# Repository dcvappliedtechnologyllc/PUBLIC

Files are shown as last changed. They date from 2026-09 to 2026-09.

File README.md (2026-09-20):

# DCV Doyle Vee Jaws — Printed Light-Vee Jaws + Keel Dock for the 4-1/2 in Bench Vise

**DCV Applied Technology, LLC** · [DCV-AT.COM](https://dcv-at.com)

Soft vee jaws for the Harbor Freight **Doyle 4-1/2 in swivel vise (item 57737)**, printed in
one piece each, that bolt on in the vise's own 1/4-20 jaw-screw holes. A 150° vee raised 2 in above the
casting holds rifle fore-ends and AR handguards on a few points of contact, a parallel band below
it clamps flat stock like the steel plates did, and a slot behind the band takes a strip of craft
foam. The dock is a double-vee block with a tee flange that hangs from the jaw tops and drops between them
and carries a swappable top — currently a PMAG stub, so an AR lower can be clamped by its magwell
without a separate vise block.

Parametric OpenSCAD plus a Python pipeline for the debossed branding. Everything regenerates from
source; change one number for a different vise.

<!-- photo: both jaws on the vise, handguard clamped -->
<!-- photo: keel dock + PMAG insert with a lower on it -->

---

## ⚠️ Read this first

- This vise makes **7,700 lb of clamping force**. These jaws are designed for a **200 lbf working
  clamp** — enough to hold a fore-end still for work, not enough to crush it. Snug the handle by
  hand. If you lean on it, the jaws will crack at the counterbores before anything else does.
- Provided **as-is, with no warranty of fitness for any purpose**. See LICENSE.
- Printed parts vary enormously with filament, moisture, printer and slicer. Nothing here
  guarantees the strength of a part you print.
- These are **soft jaws**. Never hammer on work held in them, never use them with the vise's
  anvil or pipe jaws in play, and never clamp anything that could go off.
- Inspect before use. Discard at the first crack at a counterbore, the flange root, or the lip.

---

## Why these exist

The steel plates that come on the vise are 4-1/2 in wide, flat, and 1-1/2 in tall. A rifle
fore-end held in them contacts on two lines, right where the finish is, and anything round rolls.
The usual fixes are magnetic rubber pads (which slide) or a dedicated gun vise (which costs more
than the vise did and takes up a bench).

A **light vee** — 150° included, only 0.27 in deep — touches a round or oval fore-end on two
short lines well below its centreline and holds it without crushing. Raising the apex 2 in above
the casting gets the work clear of the vise body so a handguard or a mag well has room around it.
Below the vee, a **parallel band** stands proud like the original plates so flat stock still
clamps parallel with no jaw change. Between the band and the vee is a **foam slot**: a strip of
2 mm craft foam stands in it and leans against the lower vee face, so finished stock never touches
plastic. The lip in front of that slot is deliberately set back from the band's clamp plane so it
never carries load and can't be crushed — it only holds foam.

The **keel dock** is the second half of the idea. A double-vee keel, the negative of the jaw vee,
drops between the jaws, self-centres as they close, and presents a pocket on top. The PMAG insert
that goes in the pocket is the magwell stub from a standard AR vise block on a base with two
captured nuts. Two 1/4-20 screws up through the keel hold it. Swap the insert, swap the fixture.

---

## What's in the box

| File | What it is | Print orientation | Support |
|---|---|---|---|
| `jaw_4.5in_R2_plain_ONEND_PRINT.stl` | Plain jaw. Print two, or one of these + one branded. | Standing on an end face (as delivered) | None |
| `jaw_4.5in_R2_plain_UPRIGHT_PRINT.stl` | Same jaw upright, if you want both jaws the same way | Upright | Under the saddle only |
| `jaw_4.5in_R2_DCV_public_UPRIGHT_PRINT.stl` | Movable jaw with the DCV wordmark and DCV-AT.COM debossed in the back wedge (cleanest artwork) | Upright | Under the saddle only |
| `jaw_4.5in_R2_DCV_public_ONEND_PRINT.stl` | Same, with 45° ceilings cut into the artwork so it prints on end with no support (strongest) | On end | None |
| `dock_keel_4.5in_v9_ONEND_PRINT.stl` | Keel dock (v9 tee-top; v7/v8 hung on a set-tab and clamped cocked — don't print them) | On an end face ("pop can") | None |
| `dock_mag_insert_PMAG_v5_PRINT.stl` | PMAG magwell insert for the keel (cloned PMAG geometry with its sloped magwell seat, on a nut-trap base). v4 was 1/2 in short and the catch never engaged | Base down | None |
| `rod_clamshell_geissele_A_ONEND_PRINT.stl` | **Draft.** Reaction-rod clamshell: two keel-profile halves that close on a Geissele Reaction Rod (Ø0.995 / 0.745 flats), flats facing the jaws, 0.030 in parting gap, two V-grooves for rubber-band preload, two loose 1/8 in register pins. 3.50 in long; sits at the front end of the jaws so the rod still reaches the barrel extension. Rev B waits on a rod-protrusion measurement | On end, both halves + pins | None |
| `jaw_S_chunk_4.5in_PA612_ONEND_PRINT.stl` | **Rev S test print.** One-piece 4.50 in jaw with the Rev S profile: full tab to the OEM pad (pad goes outboard, proud of the band), 9/32 mounting holes, three 3/8 holes on the through-bolt column. Fit-checks the pad-as-washer idea before the steel plates are ordered. Tab assumes a 0.30 in pad | On end | None |
| `jaw_plate_S_DRAFT.dxf` | **Concept.** Laser-cut 1/4 in steel plate for the Rev S segmented jaw (four per jaw between three printed segments). Outline generated by `CAD/jaw_plate.py`; draft until the OEM pad is measured | — | — |
| `jaw_hole_pattern_R2_test_plate_PRINT.stl` | 0.2 in coupon of the Rev R2 slot pattern (2.40 centres, 9/32 holes) — print first to check your screw spacing | Flat | None |
| `vise_handwheel_E_PRINT.stl` | 6-1/2 in handwheel that clips over the vise's sliding T-bar, full DCV logo and a LEFTY LOOSE / RIGHTY TIGHT arrow arc debossed in the face (bonus part, see below) | Face down | None |
| `vise_handwheel_D_plain_PRINT.stl` | Same wheel, plain face | Face down | None |
| `Doyle Jaws 4.5in J - claude PETG+ proto.3mf` | OrcaSlicer project: PETG proto plate, plain jaw on end + branded jaw upright, P1S 0.6 mm | — | — |
| `Doyle Jaws 4.5in Q + PMAG insert - claude PA612-CF15.3mf` | OrcaSlicer project: the nylon jaw plate — both jaws on end, PA612-CF15 presets baked in (as printed 2026-09-09: 5 walls, 40 % 3D honeycomb) | — | — |
| `PMAG insert - claude PA612-CF15.3mf` | OrcaSlicer project: the insert alone, same presets | — | — |
| `Doyle keel v9 + PMAG insert v5 - claude PET-CF17.3mf` | OrcaSlicer project, sliced: keel v9 on end + insert v5, Polymaker PET-CF17 presets baked in (0.24, 4 walls, 30 % 3D honeycomb, 15 mm³/s, 8 mm brim). 4 h 55 m, 259 g | — | — |
| `Polymaker PET-CF17 @BBL P1S 0.6mm Claude.json` | The PET-CF17 filament preset on its own, importable in Orca | — | — |

The jaws are handed only by the artwork. A plain jaw fits either side. The branded jaw reads
correctly on the **movable** jaw (wedge toward the operator); put it on the fixed side and it
reads from the back of the bench, which is fine if that's where you stand.

<!-- previews/jaw_revJ_public_views.png -->

---

## Hardware

All 1/4-20. The vise's own jaw screws are 1/4-20 button heads (5/32 hex) — they are just too short.

| Qty | Part | Where |
|---|---|---|
| 4 | 1/4-20 × **3/4 in** button-head socket cap screw (5/32 hex) | jaws. The casting's holes are blind and only ~0.2 in deep: 3/4 in through the 0.475 in wall + fender is right; a 0.35 in wall (Rev Q) let 3/4 in bottom out; 1 in and 1-1/4 bottom out. |
| 4 | **1/4 in fender washer, 1 in OD** (5/16 hole), ~1/16 thick | under the button heads — the big washer is what carries the prying load. Its bottom edge hangs 0.15 in below the jaw, over air past the casting's ~3/8 in ledge. A 3/4 in OD SAE flat washer also fits the pocket. |
| 4 | 1/4 in SAE flat washer (the ones that came on the vise are fine) | between the button head and the fender washer — a 1/4-20 button head is only 0.44 in across and a fender washer's hole is 5/16, so this bridges it |
| 2 | 1/4-20 × 1-1/4 in button-head socket cap screw | keel → insert, from below, no washer (the head bears in a Ø0.52 bore) |
| 2 | 1/4-20 hex nut (7/16 AF) | dropped down the insert's hex pockets |
| — | 2 mm craft foam, cut 4-1/2 × ~1-1/4 in | foam slot |
| 2 | 3/16 in (4.8 mm) cable tie, 8 in | handwheel |

---

## Key dimensions

Jaw 4.50 L × 3.75 H × 1.54 D (in). Jaw length equals the casting's plate seat, so the ends line
up with the casting sides.

| Feature | Value |
|---|---|
| Vee | 150° included (faces 15° off vertical), 0.27 deep, apex fillet 1/16 |
| Vee span | ±1.00 about the apex |
| Apex height | 2.75 above jaw bottom = 2.00 above the vise top |
| Mounting face to apex | 0.60 |
| Back wedge | 0.35 deep at the saddle, tapering to nothing at the top (82° face) — carries the artwork |
| Saddle | 0.35 over the casting top × 0.40 thick (the casting only has ~1/4 in of flat behind the face before it rounds off); 0.06 relief at the inside corner for the casting's edge radius |
| Parallel band | 0.325 proud of the vee-edge plane, jaw bottom to 1.45 up |
| Foam slot | 0.10 wide × 0.30 deep, against the vee |
| Lip | 0.145 thick, top flush with the lower vee edge, face 0.08 **behind** the band clamp plane |
| Screw pattern | 2 × slots on **2.40** centres (measured: 1.05 from each end of the seat), 0.35 above the jaw bottom; Ø9/32 through, ±1/8 horizontal, **±0.04 vertical** so the machined ledge sets the height and the saddle just lands on the casting |
| Washer pocket | Ø1.06 for a 1 in fender washer, open through the jaw bottom, **0.475** of plastic behind the washer (in compression; sized so a 3/4 in screw fills the casting's blind hole). On end, the pocket ceiling is a single 45° plane ("shed roof") from the vee-side tangent point up through the open jaw bottom, so every layer grows off the solid vee side; upright, it is a teardrop toward the vee. `pocket_roof = "auto"` picks. Rev Q pointed a teardrop at the vee in both orientations and the on-end pockets drooped; the far pocket's plane runs out the jaw end 0.21 in up, which is cosmetic |
| Edges | Lengthwise edges eased: 1/16 chamfers on bed-side edges, 1/16 fillets on top/vee/band edges; slot floor sharp; end edges 1/16 chamfer |

| Keel | Value |
|---|---|
| Length | 4.50 |
| Width | 2.50 across the apex line, 1.96 at the flange, 2.97 over the flanges; 1.89 tall (bottom trimmed 0.30 below the apex line, flange 0.20 above) |
| Pocket | 2.64 × 1.34 × 0.15 |
| Screws | 2 × Ø9/32 on 1.60 centres, Ø0.52 head bores 1.24 deep from the bottom, 0.50 web under the head |
| Tee flange | 0.50 reach × 0.20 thick both sides, full length; rests on the jaw tops |
| Lift | Keel apex 0.015 above the jaw apex when the flange is down → upper vee faces engage first; lower faces get 0.008 total clearance |
| Lower faces | 0.70 long (bottom trimmed 0.30); keel bottom sits 0.30 above the jaw lips. No tab, no reliefs |

| Insert | Value |
|---|---|
| Base | 2.64 × 1.34 × 0.40 |
| Seat | The source block's 11° sloped shoulder, 0.52 tall at the mag's front tapering to nothing at the rear — the rake of the magwell mouth, so the lower sits flat with the stub fully home. Catch notch 2.1–2.3 above the pocket floor |
| Height | 3.43 over the pocket floor |
| Nut pockets | 2 × 7/16 AF hex (+0.01 clearance), from the base top out the top of the stub — nuts drop in from above |

### Handwheel

Not part of the jaw system, but it lives on the same vise. A 6-1/2 in scalloped disc, 0.47 in thick, with a
Ø1.51 in bore that slides over the vise screw's Ø38 mm hub from the front and a rib across the back carrying
an open channel that drops over the Ø15 mm sliding T-bar on both sides of the hub. The hub locates it, the
bar drives it, and two cable ties (through the plate, across the channel mouth, back through — one each
side of the hub) hold it on. The bar is captured centred, so the ball ends stick out past the rim as spinner
knobs and the scallops are the palm grip. The hub pokes out through the front by however far the bar sits
back in it; nothing has to be measured. Six crush ribs in the bore stand 0.016 in proud each side — tap the
wheel on with a mallet and it stays put. The rib walls stop 0.02 in below the bar top so the ties cinch onto
the bar rather than hovering over it. Prints face down, no support, ~4 oz.

Rev E carries the face art: the full DCV logo in the lower half and "◄ LEFTY LOOSE ▪ RIGHTY TIGHT ►" arced
over the top, debossed 0.027 in (first layer plus two 0.24 mm layers, so the floors land on a layer line).
The words are on the *top* arc on purpose — up there the reader's left is counter-clockwise and right is
clockwise, so the arrows point the way the wheel turns. The art is cut mirrored by `handwheel_face.py`
(manifold3d) from the plain Rev D STL, so it reads correctly off the build plate. Rev C was printed and
fitted; D fixed the bore fit and rib height, E added the face.

**Opening.** The vise opens 4-1/2 in between its steel plates. With the printed jaws the apex
line opens roughly 1.2 in less than the bare seat-to-seat distance and the band faces 2.4 in
less. Round stock seats in the vee before the bands meet down to about 1.15 in diameter; below
that use the band flats.

---

## Design basis

Working load **200 lbf** at the apex line, taken as a cantilever from the casting top.

| Member | At 200 lbf | Comment |
|---|---|---|
| Bending in the block at the casting top | ~1,600 psi | 4.5 × 1.19 section, wedge trimmed to 0.35 |
| Saddle bearing on the casting top | ~450 psi | on the casting's ~1/4 in flat |
| Screw tension (prying, both screws) | ~250 lbf each | a grade-5 1/4-20 proofs at ~2,700 lbf |
| Washer bearing on the plastic | ~350 psi | 1 in fender washer on 0.475 of plastic (3/4 in: ~600). With only the small washers the vise ships with it is ~3,000 — use the big ones. |

Loads at the top of the vee instead of the apex are 1.5× these. Against PETG that's a margin of
about 15 on the washer bearing with the 1 in washers and only ~2 with small ones — which is why the working load is 200 and not 500, and why the big washers are not optional. CF nylon roughly
doubles it.

**Load path is designed in-plane.** Every feature is part of one extruded profile, so the plain
jaw prints **standing on an end face** with the layer lines running the length of the jaw, and
the bending stress from clamping never crosses a layer boundary. The branded jaw prints upright
for the sake of the artwork; the clamp load then pulls across layers, and the on-end branded
variant exists for anyone who wants the strong orientation with the mark.

**The lip carries nothing.** Its face sits 0.08 behind the band's clamp plane, and round stock
rides the vee faces above it. A flat piece against the band never reaches it. Earlier revisions
put the lip flush with the band and it was the one thin feature in the load path; setting it back
was cheaper than making it strong.

**The keel hangs from the jaw tops and is clamped by the upper vee faces only.** The tee flange
sets its height on both jaws, flat on flat, so roll and pitch are fixed before the handle moves.
The apex is set 0.015 above the jaw apex: raising a hexagon closes its upper faces and opens its
lower faces by lift × tan 15°, so the upper faces always touch first and their reaction pushes
the keel down onto the flange. Push down → flange → jaw top → saddle → casting; pull up → the
upper wedge tightens. The lower faces are a 0.008 backup. v1–v8 hung on a one-sided set-tab
in the foam slot instead: the keel tipped about 4° on the tab with the vise open and sat 0.04 low,
and a 15° vee (centring component tan 15° = 0.27) cannot out-pull PETG-on-PETG friction
(0.3–0.5) to fix that, so it clamped cocked. A light vee holds a seated keel; it will not seat one.

---

## Printing

Developed on a Bambu P1S, 0.6 mm hardened nozzle, OrcaSlicer. Presets and the sliced plate are in
the 3MF.

| Setting | Jaws, PETG proto | Jaws + insert, PA612-CF (as printed) | Keel |
|---|---|---|---|
| Layer | 0.24 mm (0.30 first) | 0.24 mm (0.30 first) | 0.24 mm |
| Walls | 3 | **5** (0.62 mm lines) | 4 |
| Infill | 20 % cross hatch, infill combination on | **40 % 3D honeycomb**, infill combination on | 30 % 3D honeycomb |
| Top / bottom | 4 / 4 | 4 / 4 | 4 / 4 |
| Support | Tree, on build plate only, branded upright jaw only | none (both jaws on end) | none |
| Brim | 6 mm outer | 8 mm outer | 8 mm |
| Seam | Back (mounting face) | Back | — |
| Speeds | — | outer wall 100, inner 150, infill 150, bridge 30 mm/s; max 9 mm³/s | as nylon, max 15 mm³/s |
| Other | — | precise outer wall on, elephant-foot 0.15, classic walls | |

PETG plate time for a pair of jaws is about 5.5 h and 282 g. The plate is flow-limited: a
0.30 mm layer height on the plain jaw saved nothing measurable, so everything runs at 0.24.

| Material | Where | Notes |
|---|---|---|
| **PETG / PETG+** | prototypes, fit checks | 250 °C, textured PEI 75 °C, fan 30–60 %. Slot, lip and screw slots are dimensioned for it. |
| **PA612-CF15** (Polymaker Fiberon) | final jaws + insert | As printed: 295 °C (290 first layer), high-temp plate 60 °C with glue, fan 0–15 % (off for 3 layers, 30 % on overhangs), no chamber control, **door open, top off**, dry 8–12 h at 80 °C and feed from a dryer. 9 mm³/s. Low moisture uptake keeps the slot and vee stable in a shop. Both jaws on end at 5 walls / 40 % 3D honeycomb plus the insert on its own plate fit one 500 g spool. |
| **PET-CF17** (Polymaker Fiberon) | keel | Compression only; no reason for nylon. 290 °C, textured PEI 80 °C first layer / 75 after with glue stick, fan 0–10 %, 15 mm³/s (PA612 ran 9), **door open** per Polymaker (enclosure not needed), dry 70 °C 8 h. Anneal 120 °C 10 h if you want the extra stiffness; not required. |
| PLA | no | Creeps under sustained clamp load at shop temperatures. |

---

## Fitting

1. Print the **hole-pattern coupon** first. Hold it against the casting with the vise's own
   screws; it should go on without forcing. The slots give ±1/8 in, which covers the scatter in
   these castings.
2. Remove the steel plates. The original screws are the right thread (1/4-20) but too short; keep them for the coupon.
3. Set a jaw on the casting: bottom down on the plate-seat ledge, saddle over the casting top, mounting
   face flat on the seat face. The ledge sets the height; the vertical slop in the slots lets the saddle
   land wherever the rough casting top is. Run in the 1/4-20 × 3/4s with the fender washers (small washer under the head, fender under that), snug, not torqued.
4. Close the vise gently until the bands meet and check the bands are parallel and the vee edges
   line up. If they don't, back off a screw and let the slot find it.
5. Cut a strip of 2 mm craft foam 4-1/2 in long, stand it in the slot, lean it back on the lower
   vee face. Trim it flush with the top.

### Keel dock

1. Drop a 1/4-20 nut down each hex pocket in the insert; it lands on the base.
2. Set the insert in the keel's pocket, run the two 1/4-20 × 1-1/4s up from under the keel.
   The head bears up on the keel web, the nut bears down on the base: base and web are clamped.
3. Pull the foam if it stands above the vee edge. Hang the keel on the fixed jaw by its flange
   (it leans on the upper vee face and stays put), close the movable jaw until the flange is down
   on both jaws and the upper faces have it. Push it down as you snug up; it should not move.

### Reaction-rod clamshell (draft, unprinted)

Same double-vee outline as the keel, split down a vertical plane with a D-channel for the rod. The rod's
vise flats face the jaws, so the clamp goes straight through the flats and the torque is taken by the flat
edges, not by friction on the round. Loop two #64 rubber bands (doubled) or 1/16 in O-rings in the grooves
so the shell stays on the rod between jobs; the pins keep the halves from shearing before the vise is on.
The shell is 3.50 in, shorter than the keel, and goes at the **front** end of the jaws: the receiver cannot
sit over these jaws (the rod is 1 in below the jaw tops), so the shell length is what's left of the rod
behind the receiver once the lugs are in the barrel extension. Measure that before printing.

---

## Designing your own fixture

`Notes/Jaw-Mechanics-Handoff.md` explains how the jaw carries load — the cantilever off the 0.75 in face, why the
screws are not the spring, the stiffness ladder from the FE study, and what a vise built for tall soft jaws would do
differently. `Notes/Fixture-Handoff.md` is the one-page version: the vee, the keel section numbers, the pocket and bolt
interface, and the print rules. Start there if you want something that docks in these jaws.

---

## Regenerating

```
CAD/
  doyle_vee_jaw.scad     jaw, every dimension in inches at the top of the file; print_orientation
                         = true rotates it on end. Renders the plain jaw.
  deboss.py              cuts the artwork: jaw STL + SVG -> branded STL, with the 45° ceiling chamfers
                         for on-end printing. --upright for the upright variant, --public for the
                         DCV-AT.COM art, --flip for the fixed-jaw text rotation.
                         needs manifold3d, trimesh, shapely.
  art_logo_public.scad   the wedge artwork (DCV wordmark + URL) -> art_logo_public.svg via OpenSCAD.
  dock_keel.scad         keel; print_on_end = true.
- `CAD/rod_clamshell.scad` → `rod_clamshell_geissele_A_ONEND_PRINT.stl` (`print_on_end = true`; both halves and two pins on one plate).
  mag_insert.py          cuts the magwell stub from a vise-block STL and adds the nut-trap base.
```

Put your own logo in: any SVG of filled paths works in `art_logo_public.scad` in place of the
wordmark. Keep strokes ≥ 1.2 mm for a 0.6 mm nozzle, ≥ 2 mm if you print on end.

Other 4-1/2 in vises: measure the plate seat (jaw length), the casting top above the seat
(`seat_height_in`), and the screw spacing (`screw_cc_in`, `screw_height_in`). Everything else
follows.

---

## Attribution

The jaw, the keel and the deboss pipeline are original to DCV Applied Technology.

The **PMAG insert**'s stub is cloned PMAG geometry — the external form of a Magpul PMAG magazine body,
reproduced so the stub fits an AR-15 magwell the way the magazine does. It was taken from an AR
magazine vise-block STL rather than modelled from scratch; `mag_insert.py` cuts the stub from that
file and adds the base, nut pockets and keel interface, which are new. PMAG is a Magpul trademark;
no affiliation.

Artwork: DCV wordmark and logo © DCV Applied Technology; URL and handwheel lettering set in Orbitron (SIL OFL).

---

## License

Copyright © 2026 DCV Applied Technology, LLC.

Licensed under the **CERN Open Hardware Licence Version 2 — Strongly Reciprocal
(CERN-OHL-S v2)**. You may use, study, modify, manufacture and distribute this design, including
commercially, provided modified versions are released under the same licence with sources
available. See `LICENSE`.

Source location for the purposes of the licence: **https://dcv-at.com**

## Trademark notice

"DCV", "DCV Applied Technology" and "Offensive Physics" are trademarks of DCV Applied
Technology, LLC. The licence covers the design, **not** the marks. If you distribute a modified
version, remove or replace the DCV wordmark and DCV-AT.COM deboss — they are source identifiers,
and leaving them on a part DCV did not produce misrepresents its origin. The artwork is a
separate SVG and a one-line swap in `art_logo_public.scad`; the plain jaw carries no mark at all.
The same goes for the handwheel: use `vise_handwheel_D_plain_PRINT.stl`, or swap `dcv_logo_poly.svg`
in `handwheel_face.py` for your own art.

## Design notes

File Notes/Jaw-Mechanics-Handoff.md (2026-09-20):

# Doyle Vee Jaws — mechanics handoff

What we learned about how a soft jaw actually carries load, written for someone who might design the next one — or the
vise under it — from a clean sheet. Companion to `Fixture-Handoff.md` (the keel and pocket interface) and the Design Log
(the blow-by-blow). Inches throughout. The numbers come from printed parts on a Harbor Freight Doyle 4-1/2 in vise
(57737) and from a 2D plane-strain finite-element model of the jaw section (`CAD/jaw_fea.py`); where a number is from
the model it says so.

## 1. What the jaw is, structurally

A soft jaw on this vise is a **cantilever off a 0.75 in tall mounting face**. That one sentence drives everything.

The casting offers three surfaces: a machined vertical face 0.75 in tall with two blind 1/4-20 holes at 0.35 in up and
2.40 in apart; a machined ledge about 3/8 in deep under it (the plate seat the OEM steel pad sits on); and a rough cast
top with roughly 1/4 in of usable flat behind the face before it rounds away. Above the top there is nothing to lean on.

Our jaw puts the vee apex 2.00 in above the casting top and the jaw top 3.00 in above it, because a rifle upper, a
handguard or a magazine well needs that clearance over the vise body. So the clamp load enters 2–3 in above the last
point of support. Everything below is about what that does.

## 2. The load path under clamp

The clamp load pushes each jaw *toward its own casting*. With the vee faces symmetric the resultant is normal to the
mounting face; with a big round object high on the upper face there is an upward component as well. The moment of
that load about the casting's top edge tips the jaw back over the casting.

Three things resist the tip:

1. **The mounting face in compression.** The jaw's back face bears on the casting from Z = 0 to 0.75. As the moment
   grows the bearing concentrates at the top edge.
2. **The saddle in compression.** The jaw hooks over the casting top (0.35 in reach, 0.40 in thick). Tipping back
   presses the saddle's rear onto the casting top. The arm is short — the flat is only ~1/4 in — but it is there.
3. **The screws in tension.** The screw axis is 0.35 in up; the pivot is at 0.75; the arm is 0.40 in. Against a load
   2.0 in above the pivot that is a **5:1 lever**: screw tension rises five times faster than clamp force *if* the
   joint opens.

The model's answer, which surprised us: with the joint preloaded even modestly (500 lbf per screw) **it never opens
under clamp load.** The clamp pushes the jaw into the casting harder than the moment pulls the bottom away; screw
tension actually *falls* as the vise is tightened (2000 → ~1200 lbf at 1000 lbf of clamp). The 5:1 lever only bites on
pull-away loads — prying a part out, a hammer blow outward — where the joint sees real tension. That is where preload
matters, and where a screw head bearing on printed honeycomb fails first (see §5).

So under clamp the screws are not the spring. What is?

## 3. Where the flex comes from (a stiffness ladder)

Apex deflection toward the casting at 1000 lbf clamp per jaw, from the 2D model, PA612-CF15 as printed (5 walls solid,
40 % 3D-honeycomb core taken as ¼ of solid modulus), ordered from softest to stiffest:

| Configuration | Apex, mil | Note |
|---|---|---|
| R2 jaw, fenders in pockets (idealised as a bonded face) | ~13 | real fenders on honeycomb are worse — local crush |
| Pad outboard, thin printed tab (0.475) | 15.2 | the band overhangs the pad with nothing under it |
| Pad outboard, tab to the band face (0.90–1.00) | 11.4 | the knee; more tab buys nothing |
| + vertical steel tie bolts through the jaw | 10.1–11.0 | prestress does nothing; steel ties buy 5–10 % |
| + 2 × 1/2 in flat-bar ribs in the section plane | 7.1 | |
| + 100 % infill instead of 40 % | 6.4 | the single biggest plastic-only lever |
| + 2 × L-ribs from 1 in bar (1 in below the vee, 1/2 in above) | 4.6 | depth cubed — the foot matters more than a third rib |
| + 4 × L-ribs | 3.3 | |
| **+ 4 × full-profile 1/4 in laser-cut plates (Rev S)** | **1.2** | infill stops mattering (1.19 vs 1.22 at 100 %) |
| Raise 2.0 → 1.5 in (plastic jaw, no steel) | 7.0 | the geometry lever, if the clearance allows it |

Three lessons in that table:

- **Prestress is not stiffness.** Bolts squeezing the plastic do not change its modulus. A steel member only helps if
  it is in the load path *as steel* — a tie on the tension side, or a rib carrying bending.
- **Depth cubed.** Any steel that stays behind the apex line (so the plastic keeps the vee) is worth far more when it
  is wide low down, where the moment is, than when it is tall.
- **Below ~2 mil the vise is the spring.** A 4-1/2 in slide in its ways plus the leadscrew moves several mil on its
  own. Past that point you are polishing the wrong part; four plates is where we stopped.

## 4. The mounting interface — lessons

- **The head must bear on something that does not creep.** A 1 in fender on 40 % honeycomb is ~0.7 in² of cells; at
  2000 lbf that is ~3000 psi and it crushes and creeps, which is exactly what "the flex is at the screws" felt like.
  Putting the OEM steel pad *outboard* — pad → printed tab → casting — spreads each screw over ~1 in² of solid plastic,
  or, with the Rev S plates, onto steel edges directly. Nose-bleed torque becomes safe.
- **Do not thin the root.** A rabbet at the casting face to save screw length is a hinge at the exact section with the
  most moment. The tab should be the full section; the pad stands proud of it.
- **A thin plastic layer in the stack is stiffer than a thick one** (compression stiffness ∝ 1/t), but that term is
  small; what matters is that the pad backs the whole band, not the tab thickness.
- **The blind holes set the screw length**, and the screw length sets how thick the stack can be. Measure hole depth
  early. A 3/4 in screw bottomed through a 0.35 in wall; two M6 flats fixed it that day; the design fix was the wall.
- **Slots versus holes.** Horizontal slots (±1/8) let the jaw find the casting's hole spacing; vertical slop (0.08)
  lets the machined ledge set the height while the saddle lands wherever the rough top puts it. Once the spacing is
  confirmed, holes locate better than slots and the pad takes the shear.
- **Preload is a take-up-the-slop lever**, not a stiffness lever. It flattens the printed face onto the rough casting
  and it is what holds the joint shut under pull-away. Plain Grade 8 nuts on a preloaded joint; no nylocks.

## 5. Material and print orientation

- **Print on end.** Every feature of the jaw lives in the extruded profile, so standing the part on its end face
  turns pockets, slots, roofs and holes into vertical walls. It also puts the layer lines *along the length*, so
  bending in the section plane never loads a layer interface — CF nylon's weak axis is the interlayer, and it is out
  of the load path.
- **"A roof is only a roof in one orientation."** A 45° ceiling that grows off solid in the upright print grows out of
  open air on end. Face-angle checks are not enough — slice it (`CAD/printcheck.py`) and look for material that has
  nothing under it a layer down.
- **Walls vs infill.** With five 0.6 mm walls the skin carries the vee; the core mostly carries compression. Going 40 →
  100 % infill halves the deflection of an all-plastic jaw and does nothing once there is steel inside. Choose infill
  by which jaw you are building.
- Materials as used: PETG for shape protos; PA612-CF15 for jaws and inserts (295/290 °C, high-temp plate 60 °C + glue,
  fan 0–15 %, 9 mm³/s, 5 walls, 40 % 3D honeycomb; door open, dryer feed); PET-CF17 for the keel (290 °C, textured PEI
  80 °C + glue, fan 0–10 %, 15 mm³/s, 4 walls, 30 %; door open).

## 6. The vee

- **15° off vertical (150° included) is a light vee.** It self-locates a round or a keel but it will not self-centre
  against friction: the centering component is tan 15° = 0.27, and plastic-on-plastic friction is 0.3–0.5. Anything
  that sits in the vee must be located *before* the handle moves. That is why the keel grew a tee flange that rests on
  the jaw tops and a 0.015 in lift so its upper faces engage first and push it down onto the flange.
- **Apex height sets the lever.** Every inch of raise is a linear increase in moment and a cubic increase in cantilever
  deflection. Put the apex as low as the clearance behind the jaw allows and no lower than the work needs.
- **The lip never bears.** The band below the vee carries a foam slot and a lip that holds a foam sheet against the
  face; nothing structural hangs on it, and the keel's history (v1–v8 cocked on a tab in that slot) is the reason.

## 7. If you were designing the vise itself

The soft jaw fights the vise it sits on. A vise built for tall soft jaws would:

- **Make the mounting face tall** — 2–3 in, not 0.75 — so the jaw is a plate bolted to a wall, not a cantilever off a
  curb. Every problem in §2–4 shrinks with the face height.
- **Put the screws high and spread them**, or use four. With the pivot at the top edge of the face, screws near the
  top have the long arm; ours sit 0.40 in below the pivot. Even two screws at mid-height on a 2.5 in face would cut the
  lever from 5:1 to about 1:1.
- **Give the jaw a keyed seat**: a machined step or a pair of dowels that take shear and locate the jaw, so the screws
  only preload. Then slots and slop go away.
- **Provide a steel backer as part of the vise** — the equivalent of our outboard pad, but designed in: a full-height
  steel plate the soft jaw bolts to, with the vise's own screws bearing on steel. That is the Rev S plate stack done
  once in the casting instead of four times in every jaw.
- **Keep the jaw tops as a datum.** The tee-flange trick only works because both jaw tops are co-planar; make that a
  machined feature and every fixture can hang from it.
- **Know the slide's own stiffness.** Ours is the floor at a couple of mil per 1000 lbf; a heavier slide or a shorter
  overhang raises the floor and makes the jaw improvements visible.

## 8. Where the numbers came from

`CAD/jaw_fea.py`: 2D plane-strain Q4 raster mesh of the section at 0.025 in, compression-only penalty contact on the
casting face, ledge and casting top, screw preload and axial stiffness at Z = 0.35, PA612-CF15 as 750 ksi solid with a
core at ¼ of that, steel at 30 Msi, 1000 lbf per jaw split on both vee faces (keel case) or high on the upper face
(big-round case). It is a section model: it cannot see local crush under a washer, and it smears ribs over the length.
Treat the ratios as solid and the absolute mils as ±30 %.

Files: `CAD/doyle_vee_jaw.scad` (jaw, Rev R2), `CAD/jaw_plate.py` (Rev S steel plate DXF), `CAD/build_revS_chunk.py`
(one-piece Rev S test jaw), `CAD/printcheck.py`, `Notes/Design-Log.md`, and the 3D viewer in `CAD/viewer/`.

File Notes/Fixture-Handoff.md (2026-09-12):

# Doyle Vee Jaws — fixture handoff

How to design something that docks in these jaws. Everything below is inches; the source of truth is
`CAD/dock_keel.scad` (keel) and `CAD/doyle_vee_jaw.scad` (jaw). Parts are modelled in mm, parameters in inches.

## The jaw vee (what you dock into)

Two printed jaws on a Harbor Freight Doyle 4-1/2 in vise (57737), 4.50 in long, each with a **light vee**:
a 150° included vee (faces tilted 15° off vertical), apex 2.00 in above the casting top, faces reaching 1.00 in
above and below the apex. The jaw top is flat, 3.00 in above the casting. Below the vee is a band with a foam slot;
the band never carries a fixture.

Frame used in every file: **X along the jaws, Y across the vise (toward the workpiece = away from that jaw's casting),
Z up.** For a fixture the useful datum is the *apex line* of the two vees; with the keel seated the apex lines are
**2.50 in apart** and the jaw tops are 0.985 in above them (see lift, below).

## The keel: the standard foot

The keel (`dock_keel_4.5in_v9_ONEND_PRINT.stl`, v9) is the negative of the two vees — a hexagon in section — with a
tee flange on top. Anything that needs to sit in the vise should either *be* a keel (same section, your own top) or
*bolt to* the keel's pocket. The numbers, in the section plane (Y across, Z up, Z = 0 at the jaw-bottom datum the
keel's own files use):

| Feature | Value | Why |
|---|---|---|
| Length along X | 4.50 | = the vise plate seat; clamps over the casting, no wing loading |
| Width at the apex line | 2.500 | the jaws close to 2.50 at apex when seated |
| Vee faces | 15° off vertical, ±1.00 from the apex line | must match the jaws |
| Width at the flange underside (0.985 above apex) | 1.972 | = 2.50 − 2 × 0.985 × tan 15° |
| **Tee flange** | 0.50 reach each side × 0.20 thick, underside 0.985 above the apex | rests on both jaw tops; sets roll and pitch before the handle is touched |
| Overall width over the flanges | 2.972 | |
| **Lift** | keel apex sits 0.015 above the jaw apex when the flange is down | upper faces engage first and push the keel *down* onto the flange; lower faces get 0.008 total clearance |
| Bottom trim | keel bottom 0.30 above the lower vee edge line | lower faces are a 0.70 backup; bottom clears the foam lips |
| Section height | 1.885 (bottom trim to flange top) | |

Rules that came from broken prints: no fin or tab into the foam slot (v1–v8 hung on one and clamped cocked); a 15°
vee cannot self-centre against plastic-on-plastic friction, so a fixture must be located *before* the handle moves —
that is what the flange and the lift do. Push down → flange; pull up → the upper wedge tightens.

## The pocket: how tops attach

The keel top has a pocket for a swappable insert, and two screws come **up from below**:

- Pocket: 2.64 × 1.34, 0.15 deep, 0.01 clearance each side, centred on the keel.
- Two 1/4-20 × 1-1/4 button heads on **1.60 c-c** along X, 9/32 clearance holes through the keel, Ø0.52 counterbores
  from the keel bottom (a 5/32 T-handle reaches them between the jaws). 0.50 in of keel web is left under the heads.
- The insert has a 0.40 in thick base that fills the pocket and two hex pockets (7/16 AF, from the top) that trap 1/4-20
  nuts: the nut bears down on the base, the head bears up on the keel web, so base + web are actually clamped.
- All hardware in this project is 1/4-20. Do not introduce M6.

So a new top = a 2.64 × 1.34 × 0.40 base (the pocket is cut 0.01 larger all round) with two nut pockets on 1.60 c-c, plus whatever you want on top of it.
Reference insert: `dock_mag_insert_PMAG_v5_PRINT.stl` (`CAD/mag_insert.py`).

## Variants on the same section

- **Reaction-rod clamshell** (Rev A, draft): the keel section split on a vertical plane with a D-channel for a rod along
  X, so the vise closes the shell on the rod; 0.030 parting gap so the clamp goes through the rod, rubber-band grooves
  for preload, a tongue-and-groove key planned for Rev B. `CAD/rod_clamshell.scad`. If your fixture clamps something
  rather than holding it, start there.
- Anything long along X can overhang the jaws; the section is what matters.

## Printing

Print keels and clamshells **on end** ("pop can", `print_on_end = true`): flange, pocket, bores and channel all become
vertical walls, no support. A roof is only a roof in one orientation and a 45° face is only printable if it grows off
solid — run `CAD/printcheck.py <stl>` before sending anything; it slices at 0.24 and reports unsupported area.
Materials so far: PETG for protos, PET-CF17 for the keel (290 °C, textured PEI 80 °C + glue, fan 0–10 %, door open),
PA612-CF15 for jaws and inserts.

## Files

`CAD/dock_keel.scad` (parameters: `keel_apex_width_in`, `flange_reach_in`, `keel_lift_in`, `bottom_trim_in`, pocket
and bolt sizes), `CAD/mag_insert.py`, `CAD/rod_clamshell.scad`, `CAD/printcheck.py`, and the 3D viewer artifact
(`CAD/viewer/doyle_assembly_viewer.html`) to see how it all sits.

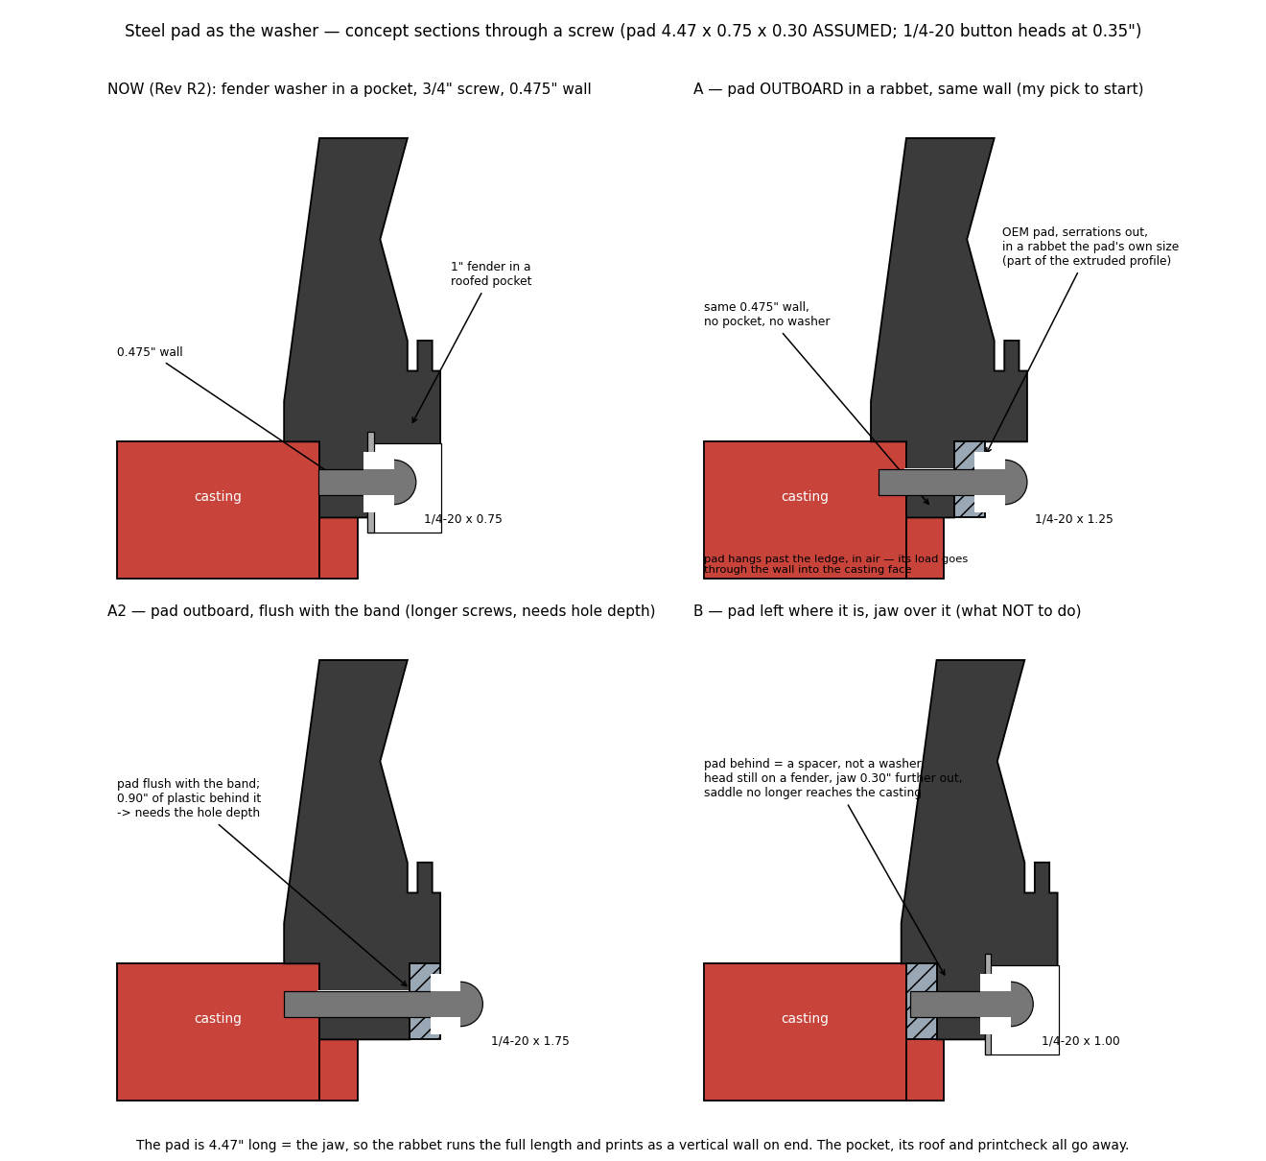
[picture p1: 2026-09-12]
CAD/previews/pad_washer_concepts.png

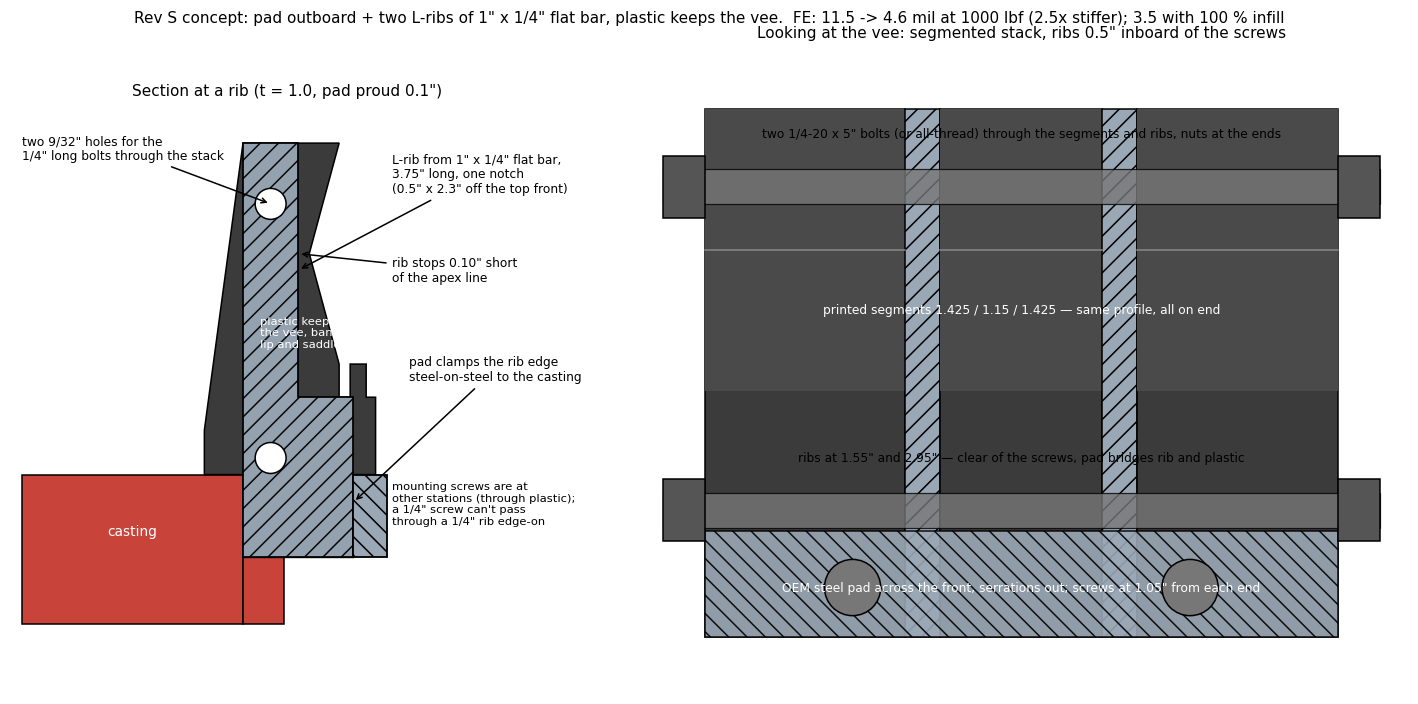
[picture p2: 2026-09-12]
CAD/previews/jaw_rib_concept.png

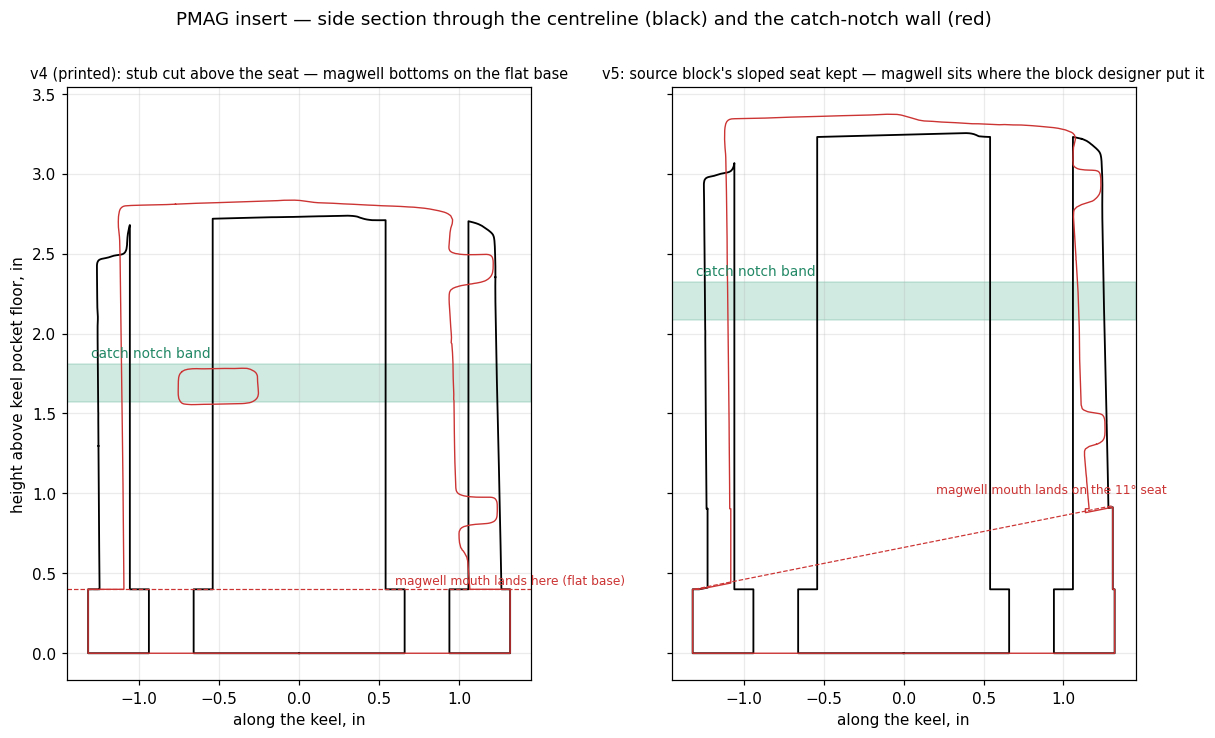
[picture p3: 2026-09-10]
CAD/previews/dock_mag_insert_v5_seat.png

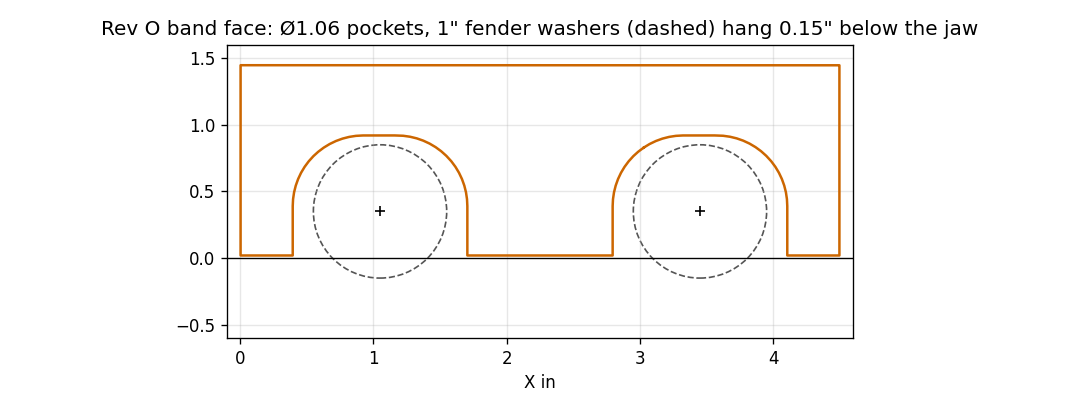
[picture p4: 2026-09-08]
CAD/previews/jaw_revO_bores.png

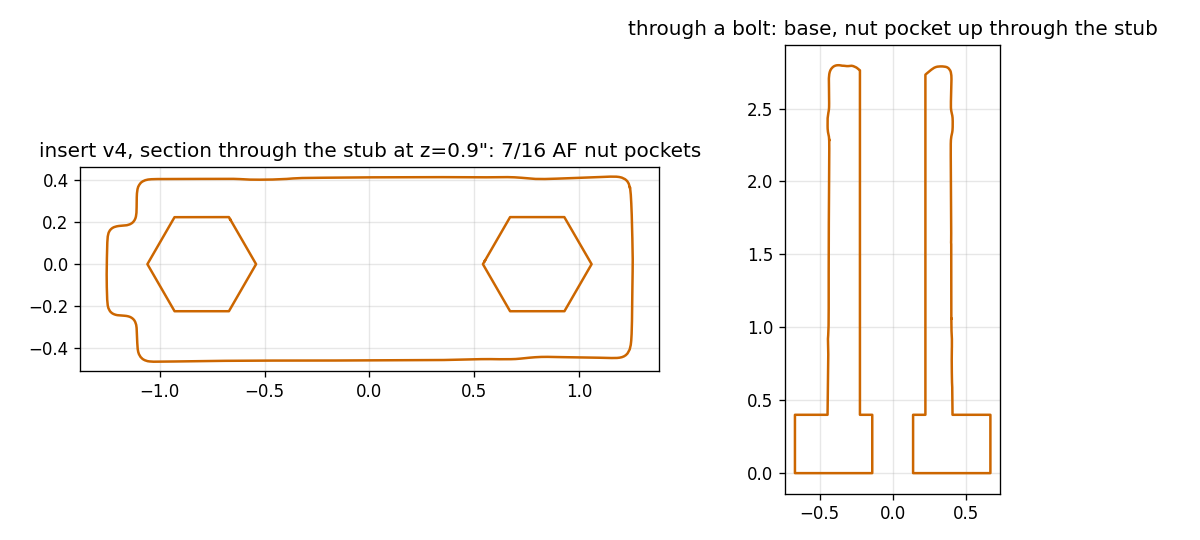
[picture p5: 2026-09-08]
CAD/previews/insert_v4_sections.png

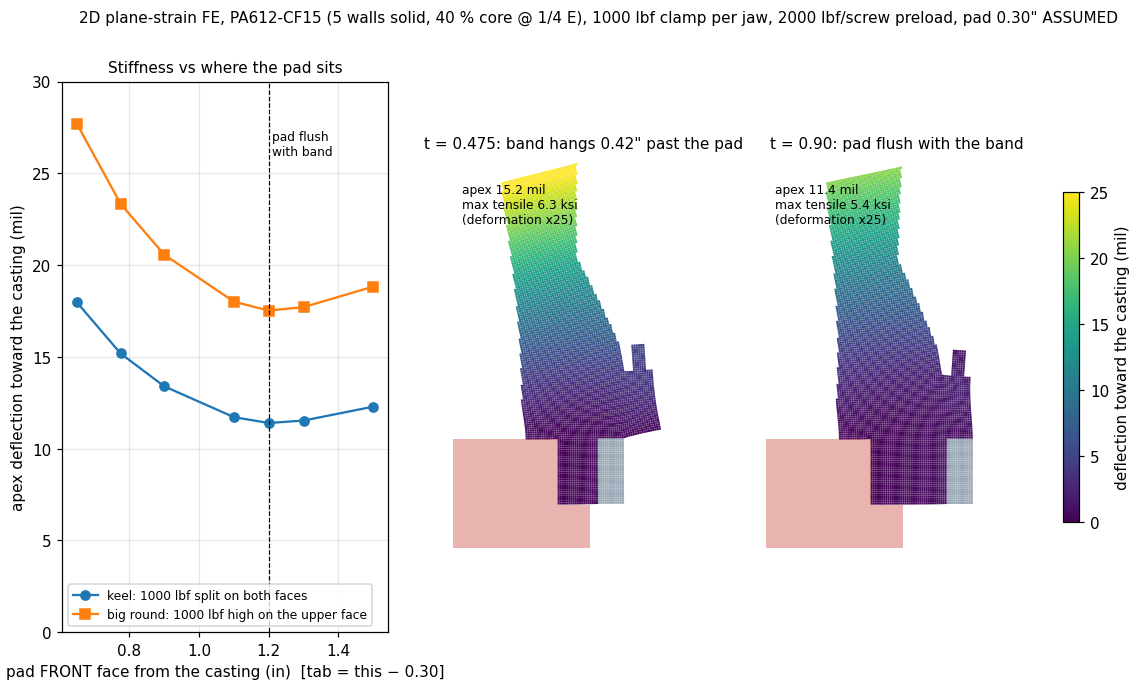
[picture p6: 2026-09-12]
CAD/previews/jaw_fea_pad_sweep.png

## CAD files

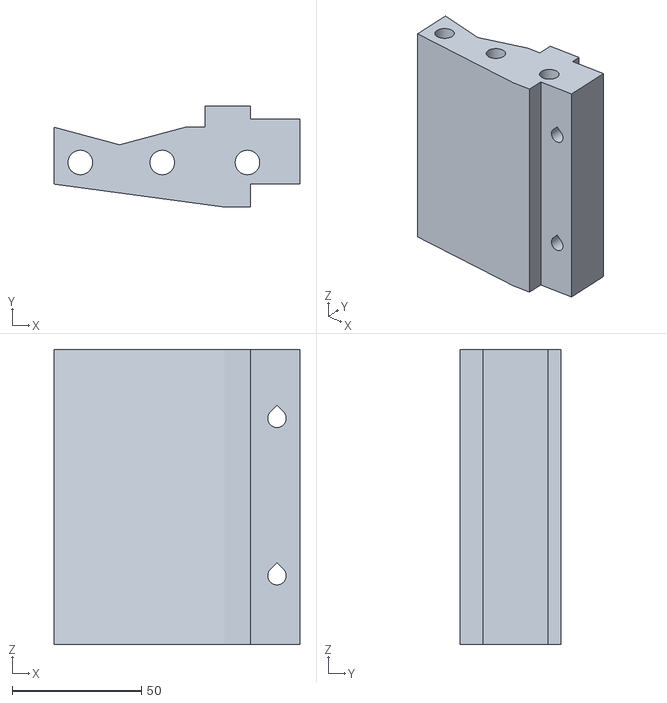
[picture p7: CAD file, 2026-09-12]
CAD/jaw_S_chunk_4.5in_PA612_ONEND_PRINT.stl
95.2 x 39.2 x 114.3

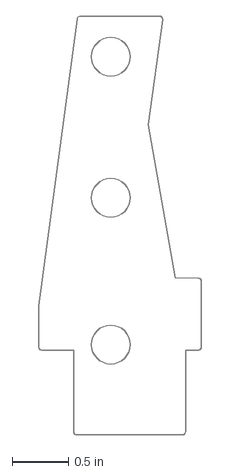
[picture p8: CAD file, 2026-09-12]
CAD/jaw_plate_S_DRAFT.dxf
1.44 x 3.71 in

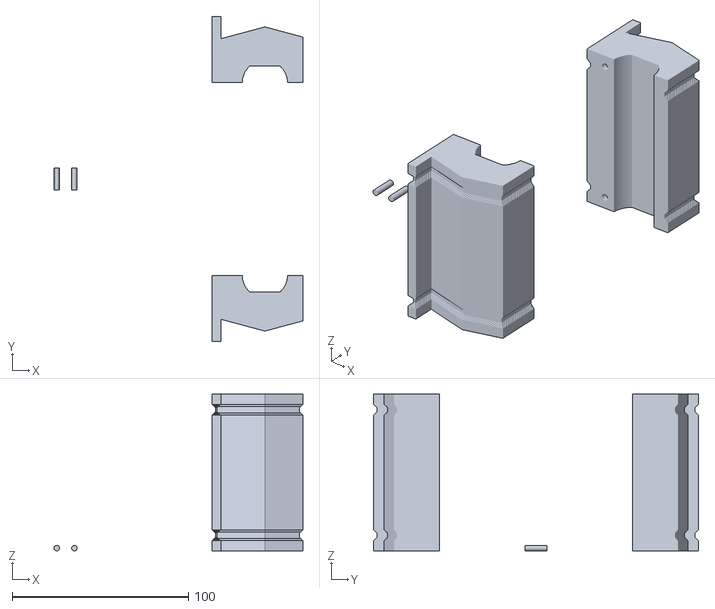
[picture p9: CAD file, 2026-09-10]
CAD/rod_clamshell_geissele_A_ONEND_PRINT.stl
141.1 x 184.4 x 88.9

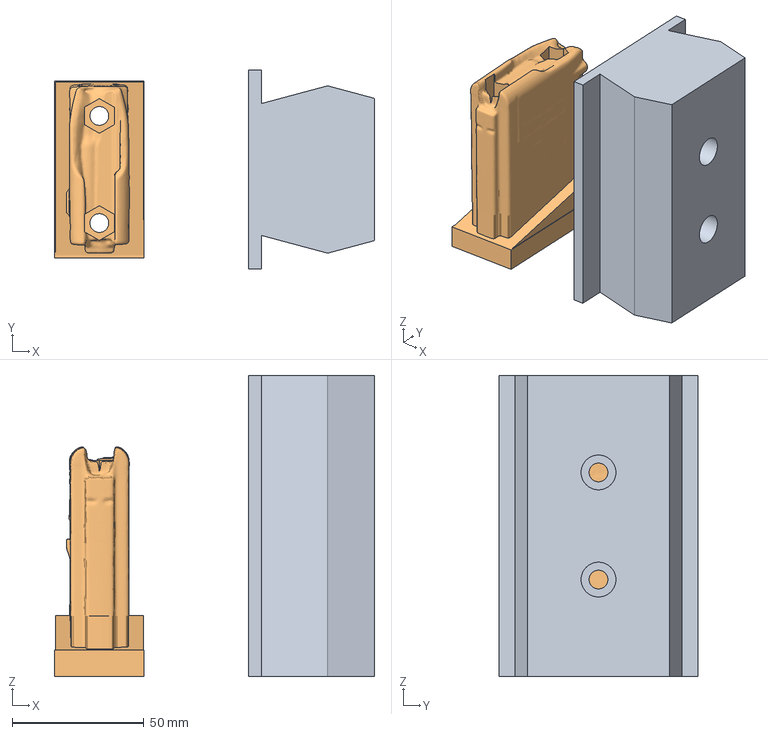
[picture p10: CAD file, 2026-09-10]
CAD/Doyle keel v9 + PMAG insert v5 - claude PET-CF17.3mf
121.4 x 75.5 x 114.3 mm
dock_keel_4.5in_v9_ONEND_PRINT.stl
dock_mag_insert_PMAG_v5_PRINT.stl

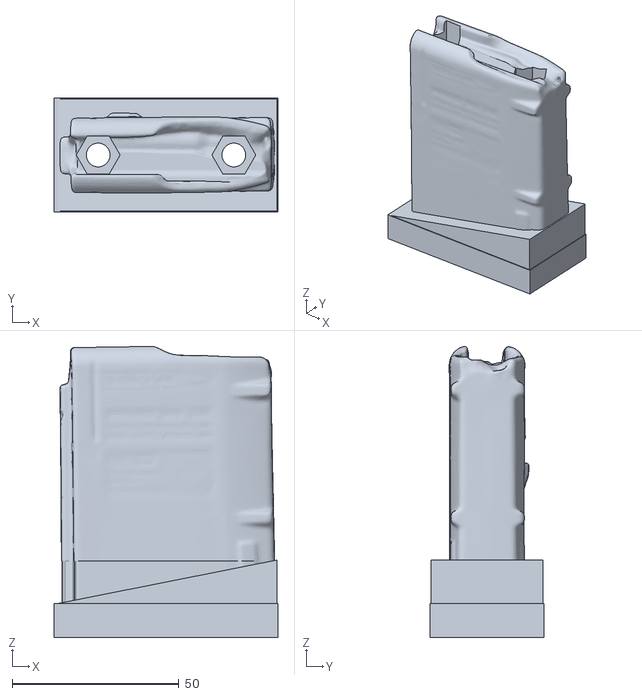
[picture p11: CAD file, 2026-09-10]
CAD/dock_mag_insert_PMAG_v5_PRINT.stl
67.1 x 34.0 x 87.2

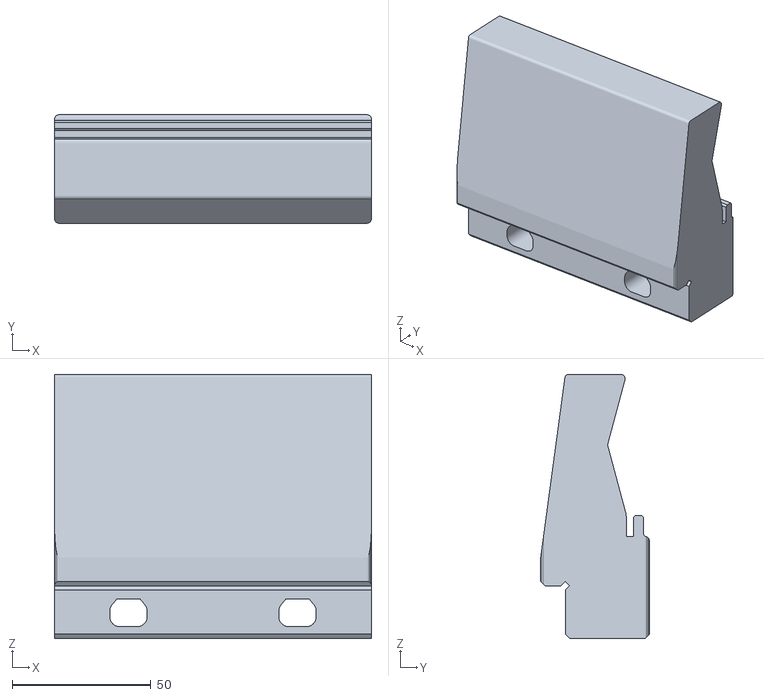
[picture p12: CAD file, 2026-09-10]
CAD/jaw_4.5in_R2_plain_UPRIGHT_PRINT.stl
114.3 x 39.2 x 95.2

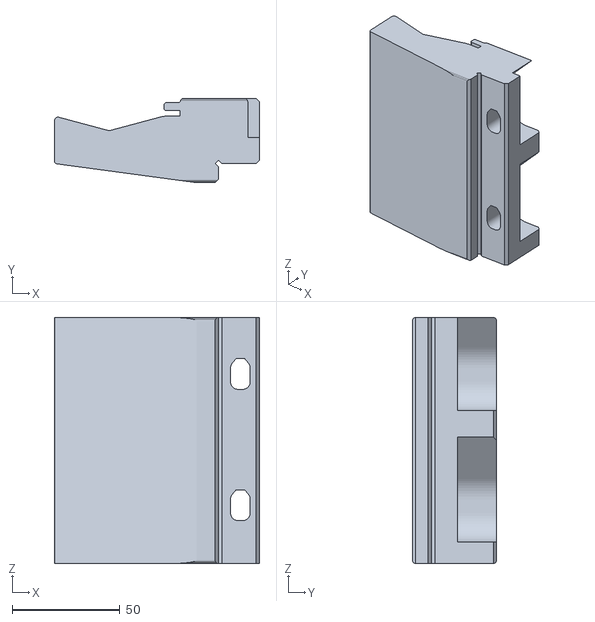
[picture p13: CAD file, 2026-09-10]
CAD/jaw_4.5in_R2_plain_ONEND_PRINT.stl
95.2 x 39.2 x 114.3

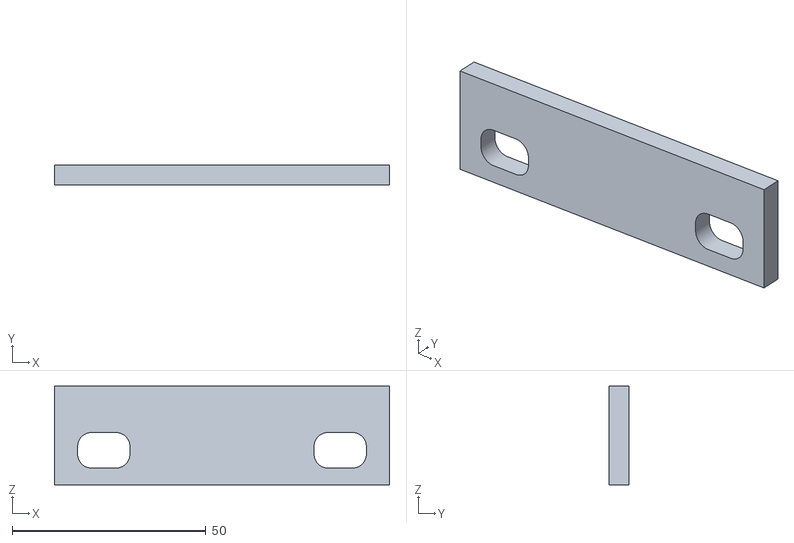
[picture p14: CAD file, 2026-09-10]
CAD/jaw_hole_pattern_R_test_plate_PRINT.stl
86.4 x 5.08 x 25.4

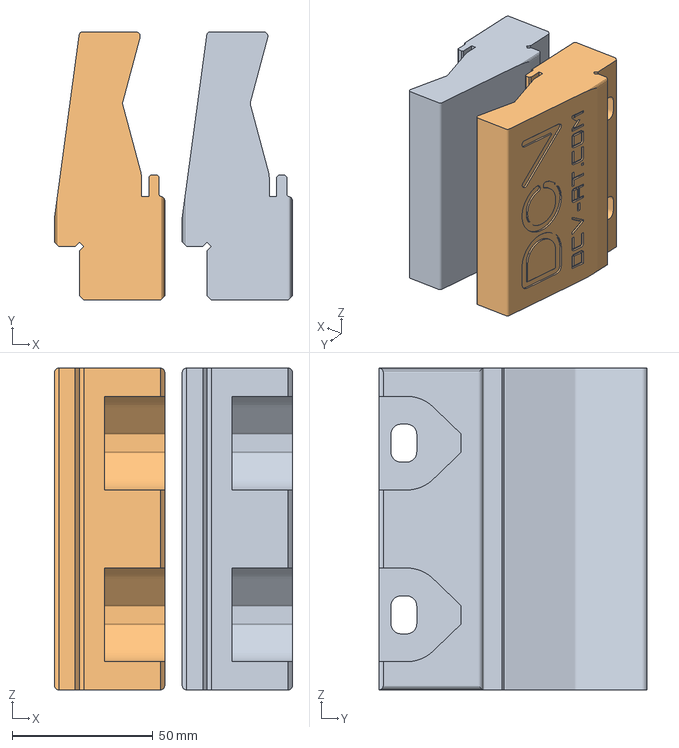
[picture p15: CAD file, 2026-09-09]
CAD/Doyle Jaws 4.5in Q + PMAG insert - claude PA612-CF15.3mf
84.5 x 95.2 x 114.3 mm
jaw_4.5in_Q_plain_ONEND_PRINT.stl
jaw_4.5in_Q_DCV_public_ONEND_PRINT.stl

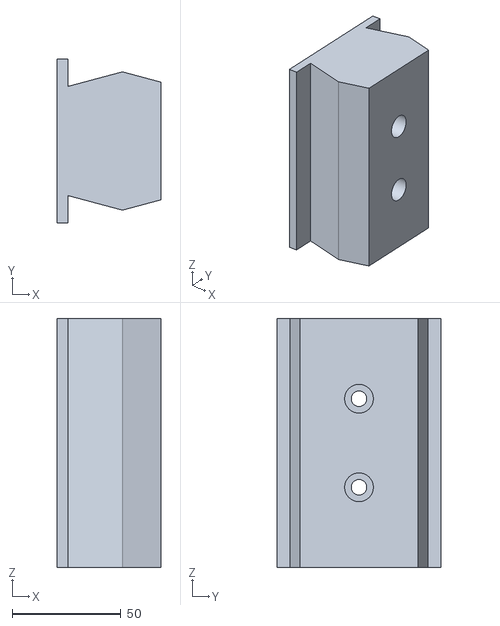
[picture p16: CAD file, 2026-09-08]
CAD/dock_keel_4.5in_v9_ONEND_PRINT.stl
47.9 x 75.5 x 114.3

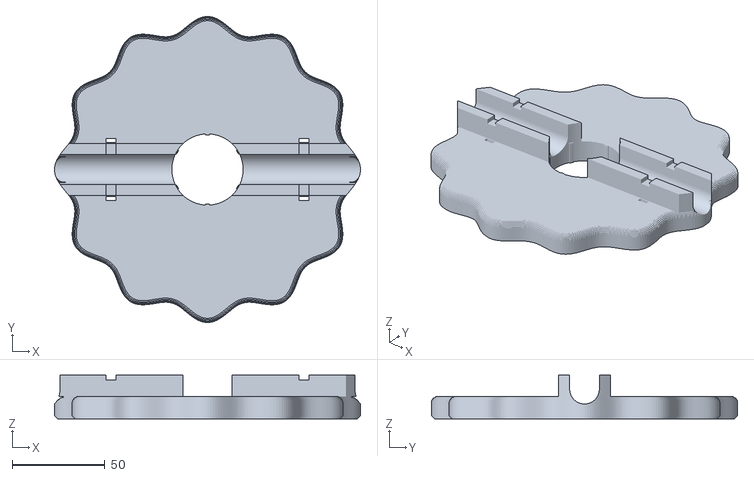
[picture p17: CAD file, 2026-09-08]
CAD/vise_handwheel_E_PRINT.stl
165.0 x 165.0 x 23.5

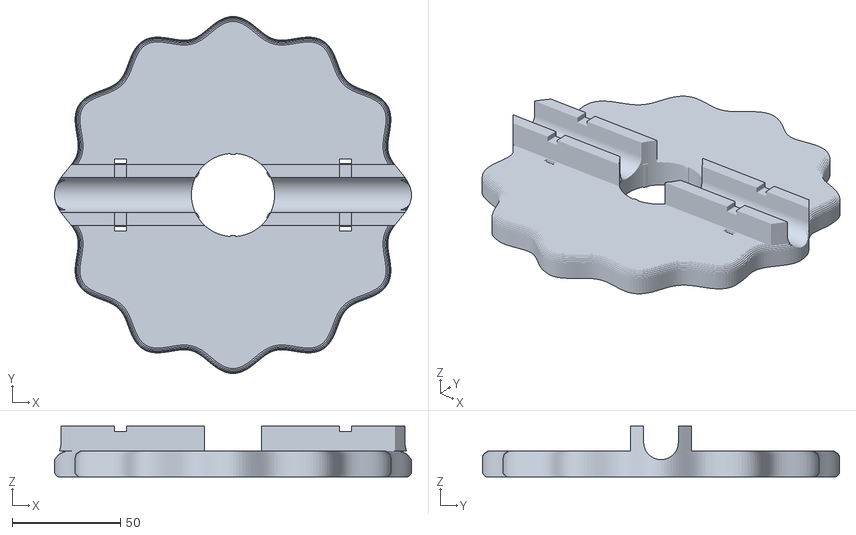
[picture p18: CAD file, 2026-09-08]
CAD/vise_handwheel_D_plain_PRINT.stl
165.0 x 165.0 x 23.5

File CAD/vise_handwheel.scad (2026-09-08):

// Handwheel adapter for the Doyle 4-1/2" vise screw — Rev D geometry (Rev C printed: bore had no interference -> tightened; bar seat
// depth was dead-on -> untouched; rib walls were taller than the bar so the ties hovered -> cut down to just below the bar top so they
// cinch on it). Rev E = this solid + face art (full DCV logo, "LEFTY LOOSE / RIGHTY TIGHT" arc) debossed 0.68 mm into the front face by
// handwheel_face.py (manifold3d), which reads the Rev D STL exported from here. Render this file plain -> vise_handwheel_D_plain_PRINT.stl.
// Slides over the Ø38 hub from the front (through bore), a rib across the back carries an open channel that
// drops over the sliding T-bar (Ø15) on both sides of the hub. Two cable ties, one each side, pass through the
// plate and across the channel mouth to hold the bar in. The hub sticks out through the front — how far depends
// on where the bar sits in the hub, so nothing here needs that number.
// PRINT FACE DOWN (front face on the bed), no support. Units: mm (the vise was measured in mm); inches in comments.

/* [Vise — measured] */
hub_dia        = 38;     // hub OD  (1.50")
bar_dia        = 15;     // T-bar OD (0.59")
ball_dia       = 24;     // ball ends, guess; only used for the preview
bar_len        = 220;    // preview only: 6-3/4" between the rubber washers + ~1" of rubber/ball each end

/* [Wheel] */
wheel_dia      = 165;    // 6.50" — 6-3/4" of bar between the rubber washers; rim stops 1/8" short of each, balls + rubber outside
plate_t        = 12;     // face plate thickness (0.47")
scallops       = 12;     // finger scallops around the rim
scallop_depth  = 4;      // radial amplitude of the scallops
front_chamfer  = 1.5;    // bed-side edge (prints as a 45deg overhang)
back_round     = 3;      // back-side rim edge fillet
hub_clear      = 0.4;    // bore = hub + this (Rev C at 1.0 + ribs came out with no interference at all)
bar_clear      = 1.0;    // channel = bar + this

/* [Crush ribs — tap-on fit on the hub. The bore stays at clearance; six small ribs stand proud of it and
   interfere with the hub, so they crush/shave as the wheel is tapped on and hold it tight. Kept clear of
   the channel (no ribs at 0/180 deg). Lead-in taper on the entry (back) side.] */
crush_ribs        = 6;
rib_interference  = 0.8;    // on diameter: rib crests sit at hub_dia - this (0.031"). Rev C at 0.4 did nothing.
rib_base_w        = 2.4;    // rib width at the bore wall
rib_leadin        = 2.5;    // taper to zero over this much of the entry side

/* [Bar rib + channel] */
rib_wall       = 6;      // channel wall thickness each side
rib_height     = 11.5;   // rib height off the back of the plate: top lands 0.5 mm BELOW the bar top (bar axis at 16, top at 23.5),
                         // so the tie notch floor (21) is under the bar crown and the tie wraps the bar instead of hovering over it
seat_depth     = 4;      // half-round seat for the bar cut into the plate's back face, so the bar nests below the rib floor

/* [Cable ties] */
tie_w          = 5.5;    // slot for a 4.8 mm (3/16") tie
tie_t          = 2.2;
tie_r          = 52;     // radius of the tie stations (mid-span of the exposed bar: hub edge is r=19.5, rim r=82.5)
tie_notch      = 2.5;    // notch across the rib walls so the strap lies flat over the channel mouth
tie_head_recess= 1.5;    // shallow recess on the front face for the strap between the two slots

$fn = 96;

R  = wheel_dia / 2;
HB = hub_dia + hub_clear;      // bore
CW = bar_dia + bar_clear;      // channel width
RW = CW + 2 * rib_wall;        // rib width
BZ = plate_t + seat_depth + 0;  // bar axis height above the front face when seated: seat bottom at plate_t - seat_depth ... see below

// Bar axis sits at z = plate_t - seat_depth + CW/2 (seat is a half-round Ø CW into the back of the plate)
bar_z = plate_t - seat_depth + CW / 2;

module scalloped_disc(h) {
    // rim: R - scallop_depth + scallop_depth*cos(n*theta)  (smooth lobes, nothing to catch a palm)
    pts = [for (i = [0 : 359]) let(t = i, r = R - scallop_depth + scallop_depth * cos(scallops * t)) [r * cos(t), r * sin(t)]];
    linear_extrude(h) polygon(pts);
}

module plate() {
    // stepped chamfer on the bed side and a stepped round on the back side (hull() would convexify the scallops)
    n = 6;
    union() {
        for (i = [0 : n - 1]) {
            z0 = i * front_chamfer / n; d = front_chamfer * (1 - i / n);
            translate([0, 0, z0]) linear_extrude(front_chamfer / n + 0.01) offset(delta = -d) projection() scalloped_disc(1);
        }
        translate([0, 0, front_chamfer]) scalloped_disc(plate_t - front_chamfer - back_round);
        for (i = [0 : n - 1]) {
            a0 = i * 90 / n; a1 = (i + 1) * 90 / n;
            z0 = plate_t - back_round + back_round * sin(a0); z1 = plate_t - back_round + back_round * sin(a1);
            d = back_round * (1 - cos(a1));
            translate([0, 0, z0]) linear_extrude(max(z1 - z0, 0.01) + 0.01) offset(delta = -d) projection() scalloped_disc(1);
        }
    }
}

module rib() {
    // full-diameter rib on the back, trimmed to the disc outline, channel down the middle
    intersection() {
        translate([-R, -RW/2, plate_t - 0.01]) cube([2 * R, RW, rib_height + 0.01]);
        translate([0, 0, plate_t - 1]) scalloped_disc(rib_height + 2);
    }
}

module cuts() {
    // through bore for the hub
    translate([0, 0, -1]) cylinder(d = HB, h = plate_t + rib_height + 2);
    // bar channel: open to the back, full length
    translate([-R - 1, -CW/2, plate_t - seat_depth + CW/2]) cube([2 * R + 2, CW, rib_height + seat_depth + 1]);
    // half-round seat for the bar, sunk into the back of the plate
    translate([0, 0, bar_z]) rotate([0, 90, 0]) cylinder(d = CW, h = 2 * R + 2, center = true);
    // cable-tie stations: two slots through the plate either side of the rib, a notch across the rib walls,
    // and a strap recess on the front face between the slots
    for (s = [-1, 1]) {
        for (t = [-1, 1])
            translate([s * tie_r - tie_w/2, t * (RW/2 + tie_t/2 + 0.5) - tie_t/2, -1]) cube([tie_w, tie_t, plate_t + 2]);
        translate([s * tie_r - tie_w/2, -RW/2 - 1, plate_t + rib_height - tie_notch]) cube([tie_w, RW + 2, tie_notch + 1]);
        translate([s * tie_r - tie_w/2 - 0.5, -(RW/2 + tie_t + 1), -1]) cube([tie_w + 1, RW + 2 * tie_t + 2, tie_head_recess + 1]);
    }
}

module crush_rib_set() {
    crest_r = (hub_dia - rib_interference) / 2;        // where the rib crest sits
    h       = HB / 2 - crest_r;                        // rib height off the bore wall
    angles  = [for (i = [0 : crush_ribs - 1]) i * 360 / crush_ribs + 180 / crush_ribs];   // straddle the channel axis, never on it
    for (a = angles) rotate([0, 0, a])
        hull() {
            // rounded crest, full height minus the lead-in
            translate([crest_r + 0.6, 0, 0]) cylinder(d = 1.2, h = plate_t - rib_leadin, $fn = 24);
            // base at the wall, full height (buried 0.5 into the wall so the union is clean)
            translate([HB / 2 - 0.5, -rib_base_w / 2, 0]) cube([1, rib_base_w, plate_t]);
            // lead-in: crest runs out to the wall at the back face
            translate([HB / 2 - 0.1, 0, plate_t - 0.01]) cylinder(d = 0.2, h = 0.01, $fn = 12);
        }
}

module wheel() {
    union() {
        difference() {
            union() { plate(); rib(); }
            cuts();
        }
        // ribs only where the bore wall exists (outside the bar seat / channel)
        difference() {
            crush_rib_set();
            translate([-R - 1, -CW/2, plate_t - seat_depth + CW/2]) cube([2 * R + 2, CW, rib_height + seat_depth + 1]);
            translate([0, 0, bar_z]) rotate([0, 90, 0]) cylinder(d = CW, h = 2 * R + 2, center = true);
        }
    }
}

module preview_vise() {   // hub + bar + balls, for the section picture only
    %translate([0, 0, bar_z - 14]) cylinder(d = hub_dia, h = 50);          // hub, end face 14 mm in front of the bar axis (guess)
    %translate([0, 0, bar_z]) rotate([0, 90, 0]) cylinder(d = bar_dia, h = bar_len - ball_dia, center = true);
    %for (s = [-1, 1]) translate([s * (bar_len - ball_dia) / 2, 0, bar_z]) sphere(d = ball_dia);
}

wheel();
if ($preview) preview_vise();

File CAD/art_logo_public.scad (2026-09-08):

// Public branded wedge art (option A): DCV wordmark over DCV-AT.COM.  Units mm; wedge face is 4.50 x 2.67 in.
in = 25.4;
wm_w = 3.60*in;          // wordmark width
url_cap = 0.34*in;       // URL cap height
gap = 0.30*in;
// wordmark bbox after resize: width wm_w, height = wm_w * 37/114
wm_h = wm_w * 37/114;
total = wm_h + gap + url_cap;
translate([0, total/2 - wm_h/2]) resize([wm_w, 0], auto = true) import("dcv_wordmark.svg", center = true);
translate([0, -total/2 + url_cap/2]) text("DCV-AT.COM", size = url_cap, font = "Orbitron:style=Bold", halign = "center", valign = "center", spacing = 1.08);

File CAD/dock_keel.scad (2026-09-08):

// Keel dock for the Doyle light-vee jaws — Rev I (v9): TEE TOP. The keel hangs from a flange that rests on the jaw tops
// instead of hanging on a set-tab in the foam slot. Rev H (v8) and everything before it hung on a one-sided 0.07" fin: with the
// vise open the keel tipped ~4deg on the fin, sat 0.04" low, and a 15deg vee (centering component tan15 = 0.27) cannot out-pull
// PETG-on-PETG friction (0.3-0.5) to fix that, so it clamped cocked. Now: flange underside sits on both jaw tops (flat on flat,
// roll and pitch fixed before the handle moves); the keel apex is set keel_lift ABOVE the jaw apex so the UPPER vee faces touch
// first and their reaction pushes the keel DOWN onto the flange ("top taper dominant"). Push down -> flange; pull up -> the
// upper wedge tightens. Bottom of the keel truncated 0.30" so the lower faces are a 0.70" backup with 0.008" clearance and the
// keel bottom clears the lip tops; set-tab and rail reliefs gone. Drops in from the top and hangs on the fixed jaw alone.
// A double-vee keel that is the negative of the jaw vee (15deg faces, 1.00" above and below the apex),
// so it drops between the jaws, self-centers when clamped, and carries a swappable top (mag insert etc.).
// Two 1/4-20 x 1-1/4 button heads come UP through counterbores in the keel bottom, into 1/4-20 nuts dropped down hex
// pockets inside the mag stub; the nuts bear on the insert base, so base + keel web are clamped.
// Print on end ("pop can", print_on_end = true): flange, pocket and bores all become vertical walls, no support.
// Units: parameters in inches, model in mm.

in = 25.4;

/* [Keel] */
keel_length_in     = 4.50;   // = the plate seat width: clamps right over the casting, no wing loading
keel_apex_width_in = 2.50;   // jaw-apex to jaw-apex when clamped (max opening at apex is 3.00")
face_angle_deg     = 15;     // must match the jaws
vee_half_height_in = 1.00;   // must match the jaws (keel is 2x this tall)
end_stops          = false;   // plates at both ends that bracket the jaw ends so the keel can't walk
stop_thick_in      = 0.20;
stop_gap_in        = 0.03;   // clearance to the jaw end faces
stop_overlap_in    = 0.50;   // how far the stops reach onto the jaw ends, each side

/* [Tee top — flange on both sides that rests on the jaw tops. The keel hangs from it. */
top_flange         = true;
flange_reach_in    = 0.50;   // how far the flange reaches over each jaw top (jaw top is 0.87" wide from the vee edge to the back wedge)
flange_thick_in    = 0.20;   // flange thickness, above its underside
keel_lift_in       = 0.015;  // keel apex sits this far ABOVE the jaw apex when the flange is down -> upper faces engage first,
                             // lower faces get 2*lift*tan(15) = 0.008" total clearance; the clamp pushes the keel onto the flange
bottom_trim_in     = 0.30;   // keel bottom raised this much: lower faces 0.70" long, bottom 0.30" above the jaw lip tops

/* [Set tab — RETIRED in v9 (kept for the record). A fin that dropped into the jaw's foam-lip groove. It hung the keel cocked. */
set_tab            = false;
tab_length_in      = 4.50;
tab_thick_in       = 0.07;
tab_clear_in       = 0.01;
tab_depth_in       = 0.26;
rail_relief_in     = 0.08;   // only cut when set_tab is on
rail_relief_wid_in = 0.30;
print_on_end       = false;  // true = stand on an end face for printing

/* [Top-piece interface — Rev B: two M6 x 30 from the TOP through ears on the insert base,
   into M6 nuts in side-entry slots in the keel (nut bears UP on keel material, so the joint actually clamps) */
pocket_len_in      = 2.64;   // insert base footprint (matches the PMAG block tang: 2.64" x 1.34")
pocket_wid_in      = 1.34;
pocket_depth_in    = 0.15;
pocket_clear_in    = 0.01;
bolt_cc_in         = 1.60;   // bolt center-to-center (inside the stub footprint, +/-0.80")
bolt_dia_in        = 0.28;   // 9/32 clearance for 1/4-20
head_cbore_in      = 0.52;   // Ø for a 1/4-20 button head (0.44 dia), from the bottom — no washer, the keel bottom is only 1.96 wide
keel_under_bolt_in = 0.50;   // solid keel web between the head and the pocket floor: 0.50 + 0.40 base + 0.22 nut = 1.12" < 1-1/4 screw

$fn = 48;

L   = keel_length_in * in;
W   = keel_apex_width_in * in;
VH  = vee_half_height_in * in;
DEP = VH * tan(face_angle_deg);
KH  = 2 * VH;                      // keel height
WT  = W - 2 * DEP;                 // width at top and bottom
ST  = stop_thick_in * in; SG = stop_gap_in * in; SO = stop_overlap_in * in;

FR = flange_reach_in * in; FTK = flange_thick_in * in; LIFT = keel_lift_in * in; BT = top_flange ? bottom_trim_in * in : 0;
ZF = KH - LIFT;                                   // flange underside = jaw top plane when seated
WF = W - 2 * (ZF - VH) * tan(face_angle_deg);     // hexagon width at the flange underside
WB = W - 2 * (VH - BT) * tan(face_angle_deg);     // width at the (truncated) bottom
KT = top_flange ? ZF + FTK : KH;                  // keel top (pocket cut from here)
Z0 = BT;                                          // keel bottom

echo(str("keel ", L/in, " x ", W/in, " (apex) / ", WT/in, " (top,bottom) x ", (KT - Z0)/in, " tall (bottom at ", Z0/in, ", flange underside at ",
         ZF/in, ", top at ", KT/in, "); overall width over flanges ", (WF + 2*FR)/in, "; lower-face clearance when seated ",
         2*LIFT*tan(face_angle_deg)/in, "; total length with stops = ", (L + 2*(SG+ST))/in));

module keel_profile() {   // in (Y, Z): hexagon, apex at Z = VH; truncated at the bottom, tee flange at the top
    if (top_flange)
        polygon([[-WB/2, BT], [WB/2, BT], [W/2, VH], [WF/2, ZF], [WF/2 + FR, ZF], [WF/2 + FR, KT],
                 [-WF/2 - FR, KT], [-WF/2 - FR, ZF], [-WF/2, ZF], [-W/2, VH]]);
    else
        polygon([[-WT/2, 0], [WT/2, 0], [W/2, VH], [WT/2, KH], [-WT/2, KH], [-W/2, VH]]);
}

TL = tab_length_in * in; TT = tab_thick_in * in; TC = tab_clear_in * in; TD = tab_depth_in * in;
RR = rail_relief_in * in; RW = rail_relief_wid_in * in;

module keel() {
    union() {
        difference() {
            union() {
                rotate([90, 0, 90]) translate([0, 0, -L/2]) linear_extrude(L) keel_profile();
                if (end_stops)
                    for (s = [-1, 1])
                        translate([s * (L/2 + SG + ST/2), 0, (Z0 + KT)/2])
                            cube([ST, WF + 2 * FR + 2 * SO, KT - Z0], center = true);
            }
            // relief over the foam-lip rails, both bottom edges (keel must hang on the vee faces, not the rails)
            if (set_tab)
                for (sy = [-1, 1])
                    translate([-L/2 - 1, sy > 0 ? WT/2 - RW : -WT/2 - 1, -1]) cube([L + 2, RW + 1, RR + 1]);
            // pocket for the top piece
            translate([0, 0, KT - pocket_depth_in * in])
                linear_extrude(pocket_depth_in * in + 1)
                    offset(r = pocket_clear_in * in) square([pocket_len_in * in, pocket_wid_in * in], center = true);
            // two bolts from below: clearance hole + deep counterbore for the head (4 mm T-handle reaches)
            for (s = [-1, 1]) {
                bx = s * bolt_cc_in * in / 2;
                translate([bx, 0, Z0 - 1]) cylinder(d = bolt_dia_in * in, h = KT - Z0 + 2);
                translate([bx, 0, Z0 - 1]) cylinder(d = head_cbore_in * in, h = (KT - pocket_depth_in * in - keel_under_bolt_in * in) - (Z0 - 1));
            }
        }
        // set-tab: fin hanging below the bottom on the -Y side, sitting in the jaw's foam slot (slot is against the vee-face
        // plane, lip is 0.10" further in, so the fin at 0.01-0.08" from the edge clears the lip). Added AFTER the relief and
        // carried 1 mm up past it into the web, so it is one body with the keel. Above the vee edge it stands in open air.
        if (set_tab)
            translate([-TL/2, -(WT/2 - TC), -TD]) cube([TL, TT, TD + RR + 1]);
    }
}

if (print_on_end) translate([0, 0, L/2]) rotate([0, -90, 0]) keel(); else keel();   // pop can: stands on an end face (bottom at Z0 is irrelevant on end)

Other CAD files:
CAD/jaw_4.5in_R2_DCV_public_ONEND_PRINT.stl
CAD/jaw_4.5in_R_plain_ONEND_PRINT.stl
CAD/jaw_4.5in_R2_DCV_public_UPRIGHT_PRINT.stl
CAD/jaw_4.5in_R_plain_UPRIGHT_PRINT.stl
CAD/PMAG insert - claude PA612-CF15.3mf
CAD/jaw_4.5in_Q_plain_ONEND_PRINT.stl
CAD/doyle_vee_jaw.scad
CAD/Doyle Jaws 4.5in J - claude PETG+ proto.3mf
CAD/jaw_4.5in_N_plain_ONEND_PRINT.stl
CAD/jaw_4.5in_N_plain_UPRIGHT_PRINT.stl
CAD/jaw_4.5in_O_plain_ONEND_PRINT.stl
CAD/jaw_4.5in_O_plain_UPRIGHT_PRINT.stl
CAD/jaw_4.5in_P_plain_ONEND_PRINT.stl
CAD/jaw_4.5in_P_plain_UPRIGHT_PRINT.stl
CAD/jaw_4.5in_Q_plain_UPRIGHT_PRINT.stl
CAD/jaw_hole_pattern_N_test_plate_PRINT.stl
CAD/jaw_hole_pattern_O_test_plate_PRINT.stl
CAD/jaw_hole_pattern_P_test_plate_PRINT.stl
CAD/jaw_hole_pattern_R2_test_plate_PRINT.stl
CAD/rod_clamshell.scad
CAD/vise_handwheel_C_PRINT.stl

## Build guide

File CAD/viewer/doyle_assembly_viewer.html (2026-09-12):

# Doyle Vee Jaws

HF 57737 · 4-1/2 in vise · jaws Rev R2 · keel v9 · insert v5 · wheel Rev E · clamshell A · Rev S concept

AssemblyCLAMPED

## Parts

## Motion

Vise opening2.50 in at apex Movable jaw, casting and screw travel; the keel stays hung on the fixed jaw.

Explode0

## View

Isometric Operator Top Side

## Display

Section at mid-length Wireframe Vise castings and screw (context only)

Drag to orbit, scroll to zoom, right-drag to pan. Geometry is the actual print STLs (insert and wheel lightly decimated); Rev S and the clamshell are concept solids. Castings are placeholders, not the real vise.

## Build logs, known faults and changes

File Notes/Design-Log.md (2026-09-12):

# Doyle Vee Jaws — design log

Why the parts look the way they do, what was tried and rejected, and what is still open.
Written so the reasoning survives without the conversation.

---

## Origin

Wanted: soft jaws for a Harbor Freight Doyle 4-1/2 in swivel vise (57737) that hold rifle
fore-ends and AR handguards on a few points of contact, print on a Bambu P1S with a 0.6 mm
hardened nozzle, and bolt on in the vise's own jaw-screw holes (thought to be M6 at the time; they are 1/4-20).

The vise was measured from ruler photos, not a drawing: plate seat 4.50 in, screw centres
~2.25 in, screw axis ~0.35 in above the plate bottom, and "4 mm hex button heads = M6" — which was wrong: a
1/4-20 button head takes a 5/32 hex (3.97 mm). The vise is imperial. That uncertainty
is absorbed by ±1/8 in slots rather than chased: "it could slide 1/8 inch and be okay."
`seat_height_in = 0.75` (casting top above the plate seat) is still an assumption to be checked
on the first fitted print.

---

## Vee geometry

150° included (faces 15° off vertical), ±1.00 in span, 0.27 in deep. For round stock of
diameter D the apex gap is 1.035·D, so the vee is shallow enough that fore-ends of 1.2–2.5 in
seat on two short lines well below centre and never touch the apex. Steeper vees were rejected:
they grip harder per pound but put the contact higher on the work and need more opening.

The apex is raised 2.00 in above the casting top so a handguard or a magwell has room around it.
Earlier revisions had the apex at the steel-plate height; the raise came from the observation
that a printed jaw can be any shape, so it may as well get the work clear of the vise body.

Contact points: "flattened pyramids" and interrupted (segmented) contact faces were considered
to save filament and cope with irregular fore-ends, and dropped — foam shims on a plain vee do
the same job with no geometry, and the user's stated preference was fewer clever features.

---

## Revision history

| Rev | Change | Why |
|---|---|---|
| A–B (8 in) | 8 in wide jaw, wings past the casting, apex at plate height | first pass; wings were for long fore-ends |
| C | Raised apex, saddle over the casting, transverse ribs on the back | ribs for stiffness with less plastic |
| C2 | **Ribs replaced by a solid back wedge** | ribs were unprintable on end — "how do those ribs support themselves in midair?" Every feature must be part of the extruded profile so it prints as a vertical wall. |
| D | Debossed branding; chamfered ceilings | OpenSCAD's CGAL could not finish the stepped cutter; moved the deboss to a manifold3d/shapely pipeline |
| F (4.5 in) | **Shortened to 4.50 in = the plate seat**; foam groove behind a lip rail | short ARs don't need wings; 4.5 in saves ~30 % filament and the ends now index on the casting sides. Keel dock and PMAG insert added. |
| G | Lip rail thinned to 0.155 | rail crush concern |
| G2/H | **Lip removed, band left as a flat shelf**; section trimmed 29 % (28.4 → 20.3 in³): back-to-apex 0.75 → 0.60, wedge 1.50 → 0.60, saddle 1.50 → 1.25 | "why not remove this? prevents that spot from ever seeing clamping load" — a flush lip was the one thin feature in the load path. Then "rethink the geometry, reduce the cross section, keep height" |
| I | **Slot back with a set-back lip**; saddle cut flush with the wedge base (tail removed); band 0.275 → 0.325 proud | the foam slot was wanted after all, but with a profile that keeps clamping load off it. Lip face 0.08 behind the band plane, 0.145 thick so it isn't fragile. The 0.65 in of saddle past the wedge did nothing structural. |
| R2 | **Shed roof on the on-end pockets** | R1's fix was wrong in the same way Q was, one step removed: a +X teardrop whose bottom-face side grew out of the open pocket — a 45°-shaped cantilever. The face-angle audit passed it. David's markup on the Q section: continue the vee-side 45° tangent line straight up through the jaw bottom, one plane, no crown. That grows off the solid vee side layer by layer, which is the direction that is actually supported. New check, `printcheck.py`, slices every layer and measures material with nothing under it: Q 733 mm², R1 517, R2 90 (all of it the 9/32 hole's 1.8 mm bridge). Far pocket's plane runs out the jaw end 0.21 in up; cosmetic, off the ledge. |
| R | **Pocket roof follows the print orientation; wall under the head 0.35 → 0.475** | Rev Q printed in PA612-CF (2026-09-09, 5 walls / 40 % 3D honeycomb) and came out "super strong", but the top corners of the pockets drooped: the Q roof pointed at the vee (+Z), which is up only for the upright print. On end, +X is up, so the pocket crown and the flat ceiling of the open-bottom notch were 90° overhangs. Audit of the on-end STL: 1,586 mm² of >45° ceiling; Rev R 23 mm² outside the intended bridges. The roof now points along print-up with a 0.40 in flat (10 mm bridge) at the apex and runs at 45° out through the jaw bottom, so the notch has no ceiling; the 9/32 hole gets a small roof too. Second finding: the 3/4 in screws bottomed in the blind holes at the 0.35 wall — the holes are ~0.2 in deep, not the 0.34 assumed at Rev P — fixed on the vise with two M6 flats, so the wall is now 0.475 (= 0.35 + 0.125). Lesson recorded in CLAUDE.md: a roof is only a roof in one orientation; audit every on-end export. |
| Q | **Teardrop roof on the washer pockets** | Orca flagged the Ø1.06 round pocket as a floating cantilever on the on-end print (its crown goes flat). A 45° roof with a 1/4 in flat at the apex fixes it in either orientation; apex 1.14 up, band top 1.45. The residual Orca warning on the on-end jaws is the 9/32 hole crown, a 7 mm bridge — ignored. |
| P | **Wall under the washer 0.50 → 0.35** | The casting's screw holes are blind: 1-1/4 bottoms out, 1 in wasn't on the shelf, 3/4 mounted but with only 0.19 of thread. The wall behind the washer is in pure compression, so it can be thin; 0.35 gives a 3/4 in screw 0.34 in (7 turns) of engagement. |
| O | Washer pockets Ø0.82 → **Ø1.06 for 1 in fender washers** | Only 1 in fenders on the shelf. Since the pocket is open through the bottom and the washer sits past the ledge, OD is free up to the pocket; 1 in hangs 0.15 below the jaw over air. Bearing ~350 psi. A small washer under the head bridges the fender's 5/16 hole. |
| N | **1/4-20 hardware throughout** (jaw, keel v7, insert v4) | The vise's jaw screws are 1/4-20, not M6 — 5/32 and 4 mm hexes are indistinguishable by eye; the pitch (20 tpi vs 1.0 mm) is the tell. Through-holes 0.26 → 9/32; washer is a 1/4 SAE flat (3/4 OD, fits the Ø0.82 pocket); insert nut pockets 10.2 → 11.4 mm AF for a 7/16 nut, ~0.19 of stub wall each side; keel head bore stays Ø0.52 (a 1/4-20 button head is 0.44), no washer there because the keel bottom is only 1.96 wide. |
| M | **Saddle and wedge 0.60 → 0.35**; vertical slot slop 0.04 → 0.08 | The casting has only ~1/4 in of rough flat behind the mounting face before the slide top rounds off, and the plate ledge is machined — so the ledge is the datum and the saddle only has to reach the flat. 11 % less plastic (19.1 → 17.1 in³), jaw 1.54 deep. Block bending at the casting top ~1,000 → ~1,600 psi, still 4× in PETG. The extra vertical slop means nobody has to get `seat_height_in` right: the jaw sits on the ledge and the saddle lands where it lands. Steeper wedge (82°) made the deboss cutter's chamfer steps touch edge-to-edge; a sub-micron jog per step in `deboss.py` keeps the output manifold. |
| L | **Screw centres 2.25 → 2.40**; pockets Ø0.82 for **20 mm** washers | Photos of the bare seat: holes 1.05 in from each end of the 4.47 in face, so 2.40 c-c — the 2.25 estimate was inside the slot range but with 0.05 to spare. The ledge under the plate is only ~3/8 in deep, so a washer 0.50 out from the face hangs over air and can be as big as the pocket allows. Bearing drops to ~600 psi. |
| K | **Washer pockets Ø0.66 for 16 mm washers, open through the jaw bottom**; vertical slot slop 0.06 → 0.04 | washer bearing was the governing number (~3,000 psi at 200 lbf on a 12 mm washer). A 16 mm washer halves it. It is the largest that fits with the screw axis 0.35 above the bottom; a 3/4 in fender washer would hang below the jaw. Ø0.66 lands tangent to the bottom face, so the pocket is opened through it rather than leaving a knife-edge sliver. Vertical through-bolts to post-tension the jaw were analysed and rejected: on end they lie in the layer plane and clamp nothing; upright they add < 200 psi of precompression that PETG creeps away, and cost section in the apex block. |
| J | Lengthwise edges eased | "she's pretty sharp." Chamfers on bed-side edges (safe overhangs upright), fillets on top/vee/band edges, 0.03 on the lip and slot mouth, slot floor sharp. End-face edges left at the plain 1/16 chamfer — a full round on a non-convex profile wasn't worth the hour. |

Dock:

| Rev | Change | Why |
|---|---|---|
| A | Keel + insert, screws from the top into nuts in the keel | **Wrong** — "does the nut actually clamp anything?" The nut had nothing to bear on. |
| B | Nuts in side-entry slots | **Wrong again** — the M6 still clamped nothing; "it would have to drop in from top" |
| C | **Screws up from under the keel into nuts dropped down hex pockets through the PMAG stub** | user's idea; the nut bears on the insert base, the head on the keel web, so base + web are clamped. Correct clamp stack. |
| D | Keel shortened to 4.50 in; set-tab in the foam groove; rail reliefs | "the base could have a mating tab to interface with the foam groove" |
| E | Set-tab full length; **keel printed on end ("like a pop can")** | tab, pocket and reliefs all become vertical walls — no support |
| v6 | Set-tab 0.10 → 0.07 | Rev I slot is 0.10 |
| v9 | **Tee top.** Flange 0.50 × 0.20 both sides rests on the jaw tops; keel apex 0.015 above the jaw apex; bottom trimmed 0.30; set-tab and rail reliefs retired | PETG v8 test: the keel cocked as the vise was tightened. Cause was the hanging geometry, not the tab per se: hanging one-sided on a 0.07 fin with 0.02 to the lip the keel tips ~4° with the vise open and sits 0.04 low; closing then has to un-roll it, lift it and slide the fin, and the fin binds diagonally in the slot at ~6°. The vee cannot fix it — tan 15° = 0.27 centring vs 0.3–0.5 friction. David's fix, obvious in hindsight: hang it from the top on a tee so it cannot fall through, and trim the bottom so the top taper dominates. Raising a hexagon by δ closes the upper faces and opens the lower ones by δ tan 15°, so with the apex 0.015 high the upper faces engage first and the clamp reaction pushes the keel down onto the flange: captured both ways (down → flange, up → upper wedge). Lower faces 0.70 long with 0.008 clearance as backup. Hangs stably on the fixed jaw alone (tipping outward lifts its own CG). Screw stack unchanged (0.50 web + 0.40 base + 0.22 nut = 1.12 < 1-1/4). |
| v8 | Set-tab unioned **after** the rail reliefs and carried 1 mm up into the web | Since Rev D the relief (0.08 high, cut last) went straight through the tab's 1 mm root, so the tab was a second, floating body in every keel STL from D to v7. Nobody had sliced a keel since the reliefs went in; caught in Orca before printing. The STL now splits into one body (`trimesh.split`) — check that on every keel export. |
| clamshell A | **Reaction-rod clamshell**, draft | David: a keel-like clamshell holding a Geissele Reaction Rod, flats up inside the bore, rubber-band preload in self-supporting double-45° grooves, keep 4.5 in. Rod 0.995 OD / 0.745 flats / 11.25 long. Parting plane vertical so the vise closes it; flats face the jaws; 0.030 gap; grooves 0.08 deep stepped one layer (0.14 ate the flange); pins loose in both halves (printed-on pins are horizontal overhangs on end). 3.50 not 4.50: the receiver can't overlap the jaws, so shell = rod behind the receiver with lugs seated − margin, ≈3.5 on assumed numbers. Unprinted; Rev B on the measurement. |
| insert v5 | **Sloped magwell seat kept under the stub** | David: "mag insert was a bit too short to engage mag catch." v4 cut the source block at z = 52, above what I had called the tang/slant transition. The slant is the magwell seat: the block's shoulder slopes 13 mm over the mag's length (11°, the rake of the magwell mouth) so the lower sits flat with the stub fully home. Standing the bare stub on a flat base left the raked mouth touching at one end with the stub ~1/2 in short, and the catch notch (30–36 mm above the stub bottom) never reached the catch. v5 cuts at z = 39 and keeps the seat; notch band 2.1–2.3 in above the pocket floor, height 2.92 → 3.43. The source STL is two overlapping shells (block + full mag body); a straight union re-merged into non-manifold edges, so the seat is rebuilt parametrically (mag cut clean at 52 on a prism of its own outline down to 39, plus the wedge) and the mag mesh decimated to 30k faces. Watertight, one body, printcheck 4 mm². |
| v7 / insert v4 | 1/4-20 | see jaw Rev N. Insert stub also sunk 0.2 mm into its base so the union overlaps instead of sharing a face (the shared face came back as non-manifold edges after STL round-trip). |

Handwheel (Rev A–E): the sliding T-bar is always off-centre and needs flipping; a disc that clips onto the
exposed bar on both sides of the hub makes it a spinner. Snap lips were drawn first and replaced by two cable
ties at the user's request — a snap fit on a Ø15 bar lives on a couple of tenths of fit, a tie does not. The
through bore means the axial position of the bar in the hub (unmeasured) does not matter: the wheel seats on
the bar, the hub pokes out the front. Channel made deeper than the estimate ("a little deeper than your guess").
`hull()` for the rim chamfer silently convexified the scallops; replaced with stepped offsets.
Rev B added six crush ribs in the bore (tap-on fit) — the first angle formula put two of them on the bar axis
where there is no bore wall, fixed with a half-pitch offset. Rev C went to 6-1/2 in (6-3/4 in of bar between
the rubber washers). **Rev C printed 2026-09-08:** bore had no interference at all (1.0 mm clearance plus
0.4 mm ribs was still loose), seat depth was "dead nuts", rib walls stood above the bar so the cable ties
hovered. Rev D: clearance 0.4, ribs 0.8 on diameter, rib height 20 → 11.5 mm so the notch floor sits under
the bar crown and the tie wraps the bar. Rev E: face art. The wordmark-only SVG looked broken at wheel scale,
so the full logo (bullet, rule, APPLIED TECHNOLOGY) went in instead, 3.5 in wide, with the 0.5 mm rule
fattened to 1.0 mm for the 0.6 mm nozzle. Direction words on the top arc, not the bottom: on a bottom arc the
reader's left is clockwise, which is exactly how a "lefty loose" mark ends up pointing the wrong way. Deboss
0.68 mm = first layer + 2 × 0.24 so the letter floors bridge on a layer boundary. Cut with manifold3d, plain
0.68 mm extrusion, no chamfer needed because the face is on the bed.

Pattern worth noting: both clamp-stack mistakes were caught by the user asking one question,
not by analysis. Draw the bolt, the nut and what each bears on before modelling.

---

## The band and the lip

The steel plates the jaws replace are flat and proud, and they clamp flat stock parallel.
Rev I's parallel band reproduces that: 0.325 in proud of the vee-edge plane from the jaw bottom
to 1.45 in. It is the only flat bearing face.

The foam slot sits above it, against the vee. The **lip** in front of the slot is set 0.08 in
behind the band's clamp plane. A flat piece against the band cannot reach it; round stock in
the vee rides the faces above it. The lip is a foam holder and a keel locator, nothing else, and
the step is big enough to be obvious by eye.

Cost of the band: round stock smaller than ~1.15 in meets the bands before it seats in the vee
(was 1.05 at 0.275 proud). Accepted; barrels go in the pipe jaws.

---

## Print orientation

Every jaw feature is in the extruded (Y,Z) profile, so the plain jaw prints **on an end face**
with no support and the clamping bend stress in-plane. The branded jaw prints upright because
the user chose to see the artwork clean — the top text is then a flat-floor recess and the
logo sits on a 77° wall where the up-slope cavity walls overhang only 13°.

On end, every stroke of the artwork has a "ceiling" in the vertical wall. Left square, the
perimeter over each cavity hangs in air for the stroke length and sags. The deboss cutter is
stepped so the ceiling side of every stroke slopes 45° over the 1 mm depth. Penalty: one edge of
each letter is bevelled ("drop shadow"), and strokes thinner than the depth become shallow
ramps. That is why the public artwork is the wordmark + URL in a heavy face with ≥ 1.4 mm
strokes, and the small "APPLIED TECHNOLOGY" tagline was dropped from it.

The fixed-jaw branded variant rotates the top text 180° (never mirrors) so it reads from the
operator's side. A mirrored first attempt "was all fucked up reverse".

---

## Slicing findings (P1S, 0.6 mm, PETG+)

- The plate is flow-limited at 15 mm³/s (uncalibrated Inland PETG+). A 0.30 mm layer height on
  the plain jaw saved **nothing** against 0.24 — the slicer slowed it back down. Everything runs
  at 0.24.
- Infill combination (two sparse layers per pass) and 3 walls instead of 4 were the real wins:
  inner walls were 30 % of plate time, sparse infill 36 %.
- Tree support **on build plate only** for the upright branded jaw: 7–8 g, 15 min. "Support
  critical regions only" sits one row below it in Orca's panel and was clicked by mistake twice.
- Pair of Rev J jaws: 5 h 30 m, 282 g (275 model + 7 support).

---

## Material

Prototypes in Inland PETG+. Final jaws + insert in **PA612-CF** (Polymaker Fiberon, 500 g
spool on hand): low moisture uptake keeps the slot and vee stable, and unlike PA6-CF it wants
the P1S chamber *cool* (door open, top off, bed 40–50 °C with glue) so no chamber heater is
needed. Keel in PETG-CF — compression only. Spool budget: jaws ~260 g + insert ~60 g fits;
adding the keel (~130 g) does not leave margin for purge and a failed start.

PA6-CF works but needs conditioning and a warm chamber; PPA-CF wants more nozzle than the P1S
has; ASA and PLA rejected (ASA for no reason to accept the fumes, PLA for creep under sustained
clamp load).

For the nylon run: both jaws on end (CF nylon's layer adhesion is its weak axis), and re-check
the slot and screw-slot fits on the PETG proto first — CF nylon shrinks differently and the lip
will be much stiffer.

---

## Rev S — steel in the jaw (concept, 2026-09-11/12)

David, looking at the R2 jaws on the vise: the flex is at the screws — "I want to be able to tighten until my nose
bleeds." First idea: keep the OEM steel jaw pad and use it as a giant washer over a printed tab, pad outboard, screws
through pad → tab → casting. A 2D plane-strain FE of the section (`CAD/jaw_fea.py`: Q4 raster mesh, compression-only
contact on the casting face / ledge / casting top, screw preload + stiffness, PA612-CF15 as 5 solid walls + 40 % core,
1000 lbf clamp per jaw) settled the arguments:

* The clamp load pushes the jaw **into** the casting; the joint never opens and screw tension *falls* under load.
  Preload is not a stiffness lever, it is a take-up-the-slop lever. The 1/4-20 mounting screws are not in the clamp
  load path; they matter only for pull-away loads and for holding position.
* A thin tab (0.475) is soft not because the tab hinges but because the band overhangs a thin pad with nothing under
  it (David's red line). Stiffness bottoms out once the pad front reaches the band face: 15.2 → 11.4 mil at 1000 lbf.
* Vertical "compression" bolts through the jaw: prestress does nothing for stiffness; as steel ties they buy 5–10 %.
* Ribs of flat bar in the section plane: 2× 1/2" bar → 7 mil; 2× L-rib from 1" bar → 4.6; 4× L → 3.3.
* **Full-profile laser-cut 1/4" plates: 4 per jaw → 1.2 mil (10× the plain jaw).** Infill stops mattering (1.19 vs
  1.22 at 100 %). Below ~2 mil the vise's own slide and screw are the spring, so four plates is where to stop.

Rev S as spec'd: jaw = plate · segment · plate · segment · plate · segment · plate, three 1.167" printed segments
(same profile, on end, 30 % is fine) and four plates, 4.500" total; the two end plates take the through-bolt heads and
nuts so nothing bears on plastic. Plate outline = R2 profile, flush on every casting-facing edge (back face, ledge,
saddle underside, tab front, band underside on the pad top), 0.06 under the work faces, 0.04 under the logo face, riser
and top. Three 11/32 holes on one column at Y 0.33, Z 0.80 / 2.10 / 3.35 (David: "the holes are illogically placed" —
they were, and a carriage head would have overhung the plate; now 5/16 SHCS on one line, the lowest one held above
the mounting-screw path at Z 0.21–0.49). Pad outboard, proud of the band 0.10, clamping the plate edges steel-on-steel.
Tab depth = band + 0.10 − pad thickness: **pad thickness not yet measured → DXF is a DRAFT.**

Hardware (McMaster, for two jaws): 5/16-18 × 5" alloy SHCS 91251A099 (×6), Grade 8 hex nut 94895A030, SAE Grade 8
washer 90126A224; mounting screws 1/4-20 Torx Plus button 90910A494 (1-3/4) / 90910A533 (1-1/2), length pending the
blind-hole depth. No nylocks (David's standing preference — plain Grade 8 nuts on a preloaded joint). Plates:
SendCutSend, mild steel 0.250", deburred, ×8.

---

## Open items — close before publication

1. **Fit on the vise.** Rev J PETG+ and Rev Q PA612-CF both fitted and clamped; 2.40 centres confirmed,
   saddle lands, bands parallel. Still to record: the true opening at the apex and between the bands, and the
   casting's blind-hole depth with a pin (R assumes ~0.2 in from the two-washer fix).
2. **PMAG vise-block source.** The insert's stub is cut from a supplied STL, "AR Magazine Vice
   Block PMAG Version Final". Author, URL and licence unknown. If it does not permit
   derivatives, ship the keel with an empty pocket and a pocket drawing.
3. **Foam.** 2 mm craft foam assumed; slot is 0.10 in. Confirm it stands in the slot and leans
   on the face without bowing.
4. **Keel float.** Confirm the keel sits 0.04 low on the tab and lifts onto the vee faces as the
   jaws close, and that the 0.07 tab clears the 0.10 slot in nylon.
5. **Keel v9 tee-top.** Confirm the flange lands on both jaw tops together (the two jaws' tops must be at the same
   height — they are located by the saddles, not the screws), the keel goes in square and stays square when snugged,
   and it cannot be pushed down or pulled up by hand once clamped. v8 (set-tab) cocked; if v9 does too, the
   problem is elsewhere (jaw tops not co-planar, or the keel printed bowed).
6. **Handwheel Rev D/E fit.** Rev C was loose on the hub; D/E have 0.4 mm clearance + 0.8 mm ribs.
   Confirm it taps on and holds, and that the ties now bear on the bar. Check the debossed
   TECHNOLOGY strokes (~0.8 mm) resolve with the 0.6 mm nozzle.
5. **PA612-CF.** Profile settled by printing, not by towers: 295/290 °C, high-temp plate 60 °C + glue,
   fan 0–15 %, 9 mm³/s, 5 walls, 40 % 3D honeycomb (David's call over the 25 % gyroid I had — better
   under the washer pockets in compression, and there was spool to spare). Jaw plate printed
   2026-09-09 on end, clean; the 0.04 in URL deboss with 45° ceilings resolved with no support.
   Insert on its own plate afterwards. Still open: weigh what's left of the spool.
6. **Keel plate.** `Doyle keel v9 - claude PET-CF17.3mf` built 2026-09-10 straight from the PA612 project
   file, then trimmed to 4 walls / 30 % 3D honeycomb / 15 mm³/s at David's call (the part is flow-limited, so
   layer height buys nothing; less plastic and more flow do), filament Polymaker PET-CF17 per their wiki:
   270–300 °C, bed 70–80, fan 0, door open. Re-sliced 2026-09-10 in Orca with insert v5 added:
   4 h 55 m, 259 g (83 m). Process saved as "… claude keel PET-CF".
7. **Clamshell Rev B.** Measure, with the barrel-extension lugs seated: rod exposed behind the receiver's rear
   face (shell length ≤ that − 0.25), where the flats start and how long they are, lug length. Then
   `rod_flat_len_in`, `flat_from_end_in`, `shell_length_in` in `rod_clamshell.scad`. Also check a #64 band
   (doubled) actually pulls the halves shut over the 0.030 gap.
8. **Rev S.** Measure the OEM pad (L × H × T, hole style, screw length) and the casting's blind-hole depth; set
   `PAD_T` in `CAD/jaw_plate.py`, regenerate the DXF, order 8 plates; cut the segment STL (R2 profile, full tab, three
   3/8 holes, 9/32 mounting holes in the outer segments only) and the Orca plate.
9. **Photos** for the README: jaws on the vise with a handguard; keel + insert with a lower.

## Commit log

2026-09-08 Doyle Vee Jaws: printed light-vee jaws, keel dock and handwheel for the HF Doyle 4-1/2 in vise
    Jaw Rev N (1/4-20, 2.40 in centres, 3/4 in washer pockets, eased edges), keel v7, handwheel Rev C,
    parametric OpenSCAD + Python deboss pipeline, README, design log, CERN-OHL-S v2.
    PMAG insert STL withheld pending the source block's licence.
    [Doyle Jaws 4.5in J - claude PETG+ proto.3mf, art_logo_public.scad, dock_keel.scad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]
2026-09-08 Add PMAG insert (cloned PMAG geometry on a nut-trap base); attribution wording
    [dock_mag_insert_PMAG_v4_PRINT.stl]
2026-09-08 Rev O: washer pockets 1.06 in for 1 in fender washers; hardware table + coupon updated
    [doyle_vee_jaw.scad, jaw_4.5in_N_DCV_public_ONEND_PRINT.stl, jaw_4.5in_N_DCV_public_UPRIGHT_PRINT.stl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]
2026-09-08 Rev P: 0.35 in wall under the washer so 3/4 in screws get 0.34 in of thread in the blind holes
    [doyle_vee_jaw.scad, jaw_4.5in_O_DCV_public_ONEND_PRINT.stl, jaw_4.5in_O_DCV_public_UPRIGHT_PRINT.stl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]
2026-09-08 Rev Q: teardrop washer pockets for the on-end print; PA612-CF15 Orca plate + presets
    [Doyle Jaws 4.5in Q + PMAG insert - claude PA612-CF15.3mf, doyle_vee_jaw.scad, jaw_4.5in_P_DCV_public_ONEND_PRINT.stl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]
2026-09-08 Handwheel Rev D/E: tighter hub fit (0.4 clearance + 0.8 crush ribs), rib walls under the bar top; Rev E face deboss with the full DCV logo and a LEFTY LOOSE / RIGHTY TIGHT arc
    Claude-Session: https://claude.ai/code/session_0175uHo1daVG29Z7SBYqAg4d
    [vise_handwheel.scad, vise_handwheel_D_plain_PRINT.stl, vise_handwheel_E_PRINT.stl]
2026-09-08 Keel v8: set-tab was a detached body since the rail reliefs went in (relief cut through the tab root); tab now unioned after the reliefs and carried into the web
    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
    [dock_keel.scad, dock_keel_4.5in_v7_ONEND_PRINT.stl, dock_keel_4.5in_v8_ONEND_PRINT.stl]
2026-09-08 Keel v9: tee top — flange hangs the keel from the jaw tops, apex 0.015 above the jaw apex so the upper faces clamp it down onto the flange; bottom trimmed 0.30; set-tab retired (v8 cocked in the PETG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
    [dock_keel.scad, dock_keel_4.5in_v8_ONEND_PRINT.stl, dock_keel_4.5in_v9_ONEND_PRINT.stl]
2026-09-09 PA612-CF15 settings as printed: 5 walls, 40% 3D honeycomb, 295/290 C, HT plate 60 C; jaw plate re-saved, insert on its own plate
    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
    [Doyle Jaws 4.5in Q + PMAG insert - claude PA612-CF15.3mf, PMAG insert - claude PA612-CF15.3mf]
2026-09-10 Rev R: pocket roof follows the print orientation (Q's pointed at the vee; on-end pockets drooped), 0.475 in wall under the head (3/4 in screws bottomed at 0.35); PA612-CF Q print report
    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
    [doyle_vee_jaw.scad, jaw_4.5in_Q_DCV_public_ONEND_PRINT.stl, jaw_4.5in_Q_DCV_public_UPRIGHT_PRINT.stl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]
2026-09-10 Rev R2: shed roof on the on-end washer pockets (one 45 deg plane from the vee-side tangent through the open bottom); R1 was a cantilever with a nice angle. Adds printcheck.py (layer-by-layer support 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
    [doyle_vee_jaw.scad, jaw_4.5in_R2_DCV_public_ONEND_PRINT.stl, jaw_4.5in_R2_DCV_public_UPRIGHT_PRINT.stl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]
2026-09-10 Keel v9 PET-CF17 Orca plate + filament preset
    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
    [Doyle keel v9 - claude PET-CF17.3mf]
2026-09-10 Keel PET-CF17 plate: 4 walls, 30% 3D honeycomb, 15 mm3/s
    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
    [Doyle keel v9 - claude PET-CF17.3mf]
2026-09-10 Insert v5: keep the source block's sloped magwell seat under the stub (v4 cut it off and sat 1/2 in short of the mag catch)
    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
    [dock_mag_insert_PMAG_v4_PRINT.stl, dock_mag_insert_PMAG_v5_PRINT.stl]
2026-09-10 Insert v5 notes in CLAUDE.md and the Design Log
    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
2026-09-10 PET-CF17 plate sliced in Orca: keel v9 + insert v5, 4h55m / 259 g
    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
    [Doyle keel v9 + PMAG insert v5 - claude PET-CF17.3mf, Doyle keel v9 - claude PET-CF17.3mf]
2026-09-10 Reaction-rod clamshell Rev A (draft): keel-profile halves with a D-channel for the Geissele rod
    Two halves of the keel v9 outline split on a vertical plane, D-channel for a 0.995 OD / 0.745-flat rod with the
    flats facing the jaws, 0.030 in parting gap, 45deg band grooves 0.08 deep stepped one layer, two loose 1/8 in
    register pins. 3.50 in long at the front end of the jaws so the rod still reaches the barrel extension.
    Unprinted; Rev B waits on the rod-behind-receiver measurement.
    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
    [rod_clamshell.scad, rod_clamshell_geissele_A_ONEND_PRINT.stl]
2026-09-12 Rev S concept: steel plates in the jaw, FE study, plate DXF draft, viewer update
    2D plane-strain FE (CAD/jaw_fea.py) of the jaw section with the OEM pad outboard: the joint never opens under clamp
    load, thin tabs are soft because the band overhangs the pad, ties/prestress buy ~5-10 %, flat-bar ribs 2-3x, and four
    full-profile 1/4 in laser-cut plates take the jaw from 11.5 to 1.2 mil at 1000 lbf. Rev S = 3 printed segments + 4
    plates on three 5/16-18 x 5 SHCS, end plates take the heads/nuts, pad clamps the plate edges to the casting.
    CAD/jaw_plate.py generates jaw_plate_S_DRAFT.dxf (draft until the pad is measured). Viewer rebuilt with R2 jaws,
    insert v5, clamshell A + rod, and the Rev S stac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
    [jaw_plate_S_DRAFT.dxf, rod_clamshell.scad]
2026-09-12 Viewer: Rev S stack + keel/insert/wheel on by default
    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
2026-09-12 Rev S test chunk: one-piece 4.5 in PA612 jaw with the pad-outboard tab and bolt column
    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
    [jaw_S_chunk_4.5in_PA612_ONEND_PRINT.stl]
2026-09-12 Notes: fixture handoff (keel section, pocket interface, print rules)
    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
2026-09-20 Notes: jaw mechanics handoff (load path, stiffness ladder, ground-up vise notes)
    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
